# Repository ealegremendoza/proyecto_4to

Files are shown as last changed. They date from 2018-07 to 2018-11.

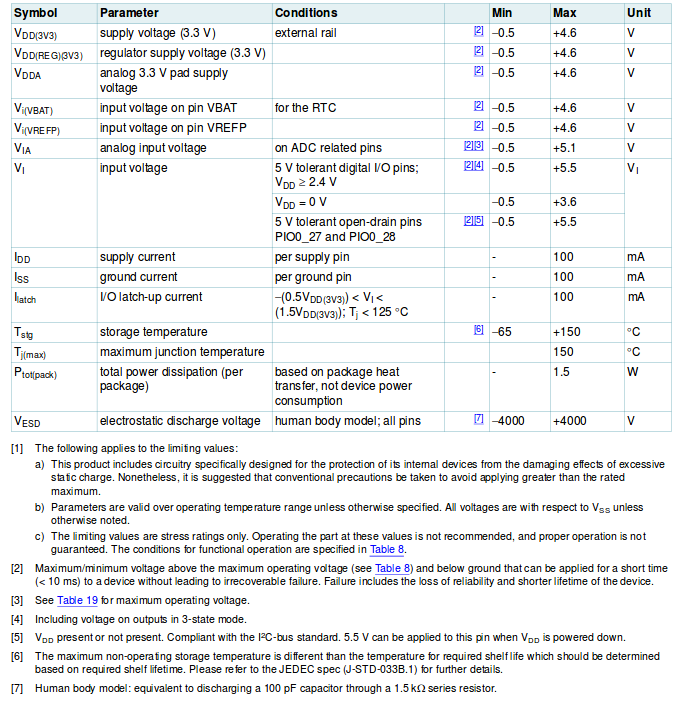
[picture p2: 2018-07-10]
docs/lpc_info/table6_limiting_values.png

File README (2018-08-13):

Este repositorio contiene gran parte del proyecto de cuarto año a de la carrera de Ingeniería Electrónica de la UTN-FRBA.

Breve descripción de las carptas 
---------------------------------------------------------------------------------------------
En la carpeta "docs" se encuentra toda documentación relacionada al proyecto.
En la carpeta "csv" se encuentran los archivos *.csv para la aplicación.

En la carpeta "code" se encuentra todo código relacionado al proyecto.
En la carpeta "code/dsp" se encuentran las clases para el procesamiento de señales.
En la carpeta "code/gui" se encuentran las clases relacionadas a la interfaz gráfica de la aplicación.

En la carpeta "pcb" se encuentra todos los archivos KiCad relacionados al diseño del PCB.

En la carpeta "lpc_info" se encontrará información útil sobre el microcontrolador utilizado.

NOTAS IMPORTANTES
---------------------------------------------------------------------------------------------

- La interfaz gráfica de este proyecto es realizada en código Python 3.6.5., bajo la plataforma ANACONDA3.
- Hoy en día el código funciona en un SO Ubuntu 16.04 LTS.
- Para correr la aplicación:

	Desde la terminal en el directorio code:
		python3 app.py 

	O desde la terminal en el directorio proyecto_4to:
		python3 code/app.py

	Desde SPYDER:
		Abrir el archivo app.py que se encuentra en el directorio code.
		Presionar F5.
---------------------------------------------------------------------------------------------

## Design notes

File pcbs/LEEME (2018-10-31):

PROYECTOS DE KICAD 4.0.7
/misc 	->	footprints, libs.

/pbase 	->	placa base con LPCXPRESSO LPC1769 REVC
/pbase-ino ->	placa base con ARDUINO MEGA
/cargador ->	placa cargadora de baterías de Litio.

placa1-3_G1.zip	-> pbase GERBERS
placa2-3_G1.zip -> cargador GERBERS
placa3-3_G1.zip	-> pbase_ino GERBERS

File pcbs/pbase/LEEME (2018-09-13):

ordenarlos documentos bien antes de entregarlo.

Todos los resistores SMD 0806

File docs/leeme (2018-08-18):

modificar esta carpeta de la siguiente manera:

/docs
	/modulos
	/misc
	/ppt
	/gantt
	/anteproyecto
	/informes
	/manuales

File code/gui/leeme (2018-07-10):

Para correr, en la terminal:

>	python app.py

IMPORTANTE:

Se uso qt designer 5.6 para hacer el *.ui  (archivo interfaz_grafica.ui)

Se uso pyuic5 para convertir este ultimo archivo a extención *.py  (interfaz_grafica_ui.py)

Se uso python 3

Se uso PyQt5

Para convertirr *.ui a *.py hacer lo siguiente:
abrir terminal en el directorio donde esta el archivo *.ui
correr:
pyuic5 test.ui -o test_ui.py

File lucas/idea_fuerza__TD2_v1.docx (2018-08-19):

Using Multiple Sensors and a LCD Display to Determine Football Players Performance

Alegre Ezequiel Mendoza¹, Tarazona Leandro¹, ², Bautista Lucas¹

¹ Universidad Tecnológica Nacional - Facultad Regional Buenos Aires, Argentina

² Grupo de Investigación y Desarrollo en Bioingeniería (GIBIO) Universidad Tecnológica

Nacional- Facultad Regional Buenos Aires, Argentina.

Abstract—. Si bien en el mercado existen productos que permiten estimar parámetros de interés en deportistas, poco se conoce sobre una aplicación que este orientada al mundo de la investigación, capaz de permitirle a un experto tener un monitoreo constante de la actividad física, sin que esta se vea alterada por el seguimiento de la misma. Por ello se busca diseñar un dispositivo portátil de conexionado inalámbrico a fin de determinar la posición, velocidad y distancia total recorrida por un jugador de fútbol en el transcurso de un entrenamiento regular. Haciendo uso de módulos de bajo coste se obtendrán las variables físicas del sujeto así como también se pretende llevar a cabo el cálculo de la incertidumbre en la medición de las mismas. Dado que los sensores proporcionan información de poca fiabilidad, se determinarán estos parámetros mediante técnicas de procesamiento de señales y filtrado digital. Luego a través una interfaz usuario se informara un valor medio de los mismos así como también se realizara el correspondiente respaldo de datos, tanto en la PC como en el dispositivo.

Index Terms—.LCD Display, GPS, ACC’s, IOT, SD Cards, Ciencia y Deportes.

          I. MATERIALES Y METODOS
               A. Diseño y requerimientos

Se propone el desarrollo de un dispositivo portátil capaz de adquirir, enviar y registrar de manera continua la posición y velocidad de un jugador de futbol. El dispositivo debe ser pequeño, funcionar a batería y permitir almacenar los datos durante todo el transcurso del entrenamiento. Para poder realizar un monitoreo de los parámetros de interés el mismo deberá poder conectarse a una interfaz usuario, de manera inalámbrica a través de una PC. El dispositivo se montará sobre el torso del deportista a examinar y para su calibración se lo colocará en una esquina del campo de juego, indicando el encargado de la interfaz usuario la esquina correspondiente. Se encenderá el equipo y, una vez que este finalice la rutina de inicialización, contará con un Display LCD a fin de informar cuando esté listo para usarse. Luego se pulsará un botón de conexión y comenzará una cuenta regresiva la cual debe mostrarse tanto en la interfaz gráfica como en el Display (de no ser así debe repetirse el procedimiento anterior), una vez que la cuenta finalice, el deportista correrá hacia el campo de juego y comenzará el monitoreo.

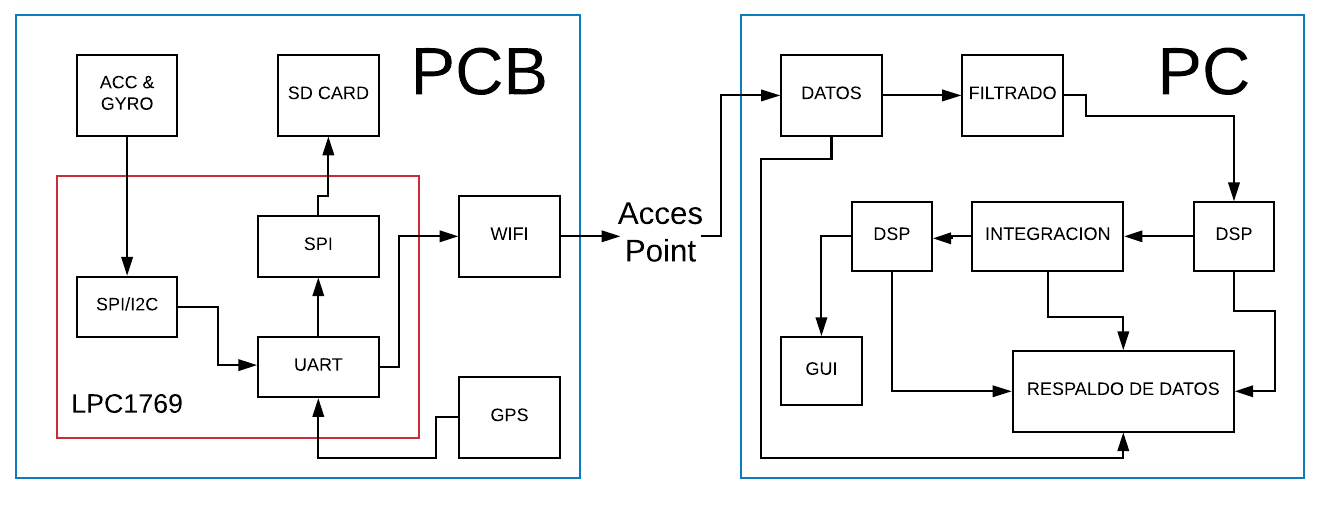
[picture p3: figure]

Fig.1 Diagrama en Bloques: Funcionamiento del Dispositivo.

               B. Hardware

Para la adquisición de las señales de aceleración se utilizará un modulo acelerómetro (MPU 6000/6050) capaz de comunicarse con un micro-controlador del tipo CORTEX M3 a través del protocolo SPI o I²C. Por otro lado la determinación de la posición relativa se obtendrá mediante un modulo GPS el cual entrega tramas de datos vía UART. Para el envió de datos del dispositivo a la PC se utilizará un modulo WI-FI el cual permite enviar tramas de caracteres a través de puerto serie. Para la recepción de los mismos se utilizará un router o acces point que cubra la distancia solicitada. El respaldo de datos se realizará con una memoria SD, la cual tendrá como propósito almacenar los datos del experimento en todo momento en caso de que el equipo sufra una desconexión y finalmente para la alimentación del dispositivo contará con una batería recargable de litio y un puerto de carga para la misma. La HMI contara con botones de acción (ON/OFF, CONNECT) y un Display LCD para informar el estado de la aplicación así como también el tiempo que transcurrió durante el experimento.

               C. Software

Una vez que los datos lleguen a la PC, haciendo uso de Python se realizará el filtrado de los datos mediante la síntesis de un filtro digital que a su vez debe ser capaz de realizar un proceso de integración sobre la variable de entrada. Es necesario efectuar dicho procedimiento ya que el sensor entrega valores referidos a la aceleración y esta se relaciona con la velocidad mediante la ecuación (1). Posteriormente, antes de informar un valor que pueda tomarse como representativo, se realizarán las correcciones correspondientes, como promedio, corrección del error numérico, etc.

a_((t)) =(dv_((t)))/(dt) => ∫ a_((t)) dt=v_((t)) =(dx_((t)))/(dt) => ∫ v_((t)) dt=x_((t))

V_((S)) =1/SA_((S)) => X_((S)) =1/SV_((S)) (1)

X_((S)) =1/S1/SA_((S)) =1/(S^2)A_((S)) (2)

Por otro lado, dado que el GPS presenta un error considerable, se intentará disminuir el mismo mediante la ecuación (2). Esta muestra la relación existente entre la posición y la aceleración, por lo cual resulta necesario hacer pasar la señal de aceleración por un filtro digital de al menos tres etapas, filtrado, integración e integración de la etapa anterior. De este modo procesando los datos del GPS en conjunto con los del acelerómetro puede disminuirse la incertidumbre en la posición del jugador. La interfaz gráfica mostrará la posición y velocidad del jugador en el campo de juego, almacenando a su vez los datos del experimento en una planilla de cálculo para su posterior análisis, el cual estará disponible para el usuario experto en procesamiento de información.

          II. PLANIFICACION DEL PROYECTO
          III. ALCANCE DEL PROYECTO PARA LA ASIGNATURA TECNICAS DIGITALES II

El equipo se compromete a: Desarrollar el hardware necesario, referido a la adquisición, transmisión y respaldo de datos, lograr un sistema embebido de funcionamiento inalámbrico, así como también contar con una interfaz humano-máquina que permita al usuario manipular el dispositivo (puertos de carga, botones de configuración, Display LCD, etc.), priorizando la funcionalidad por sobre el tamaño, estética y practicidad del mismo. Utilizar un micro-controlador del tipo CORTEX M3 para su elaboración. Programar una interfaz gráfica, hecha en Python que reciba los datos del dispositivo e informe al usuario del valor de estos, generando a su vez un respaldo de los mismos. Total transparencia en el armado de la aplicación (circuitos, algoritmos, módulos, código, etc.

Firma Integrantes: …………………………………………………………………………………………

Firma Docentes: ………………………………………………………………………………………....

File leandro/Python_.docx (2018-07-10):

Probar instalando directamente anaconda por este link

https://www.anaconda.com/download/#windows

1 - Instalar Python 2

https://www.python.org/downloads/

2 - Instalar paquetes

Abrir consola de windows y utilizar los siguientes comandos

python -mpip install -U pip
python -mpip install -U matplotlib

3 - Implementar los paquetes

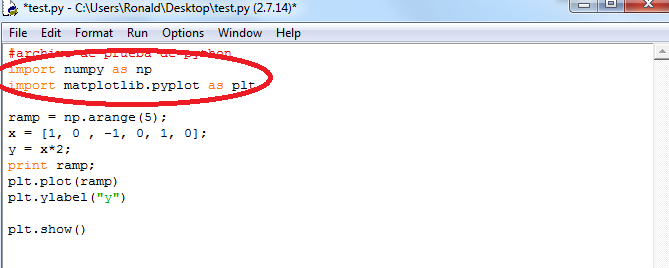
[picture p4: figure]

4 - Utilizar matplotlib y numpy

5 - Para ayuda con sintaxis y otras cosas revisar el Help-> PythonDocs o code academy :

https://www.codecademy.com/learn/learn-python

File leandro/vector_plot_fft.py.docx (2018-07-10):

#archivo de prueba de python

import numpy as np #libreria de matrices

import matplotlib.pyplot as plt #para plots

import scipy.fftpack # para fft

N = 20

ramp = (np.arange(N))/float(N); #creo un vector con una rampa creciente de 0 a 1

ramp_fft = scipy.fftpack.fft(ramp, N , 0); #FFT de la rampa

## Creacion de los gráficos ###############################

# Seteo un tamaño mas grande para los graficos

plt.rcParams['figure.figsize'] = (20,10)

# Grafico de la rampa

fig1, ax = plt.subplots()

ax.plot(ramp)

plt.ylabel("ramp")

# Grafico del modulo de la fft de la rampa

fig2, bx = plt.subplots()

bx.plot(abs(ramp_fft))

plt.ylabel("fft")

plt.show()

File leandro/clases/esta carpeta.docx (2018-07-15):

Los siguientes archivos son ejemplos de clases en python.

No estan comentados pero estan listos para correr.

El archivo .ipynb es para abrir con jupyter

los otros dos son los archivos listos para usar en spyder o python a secas.

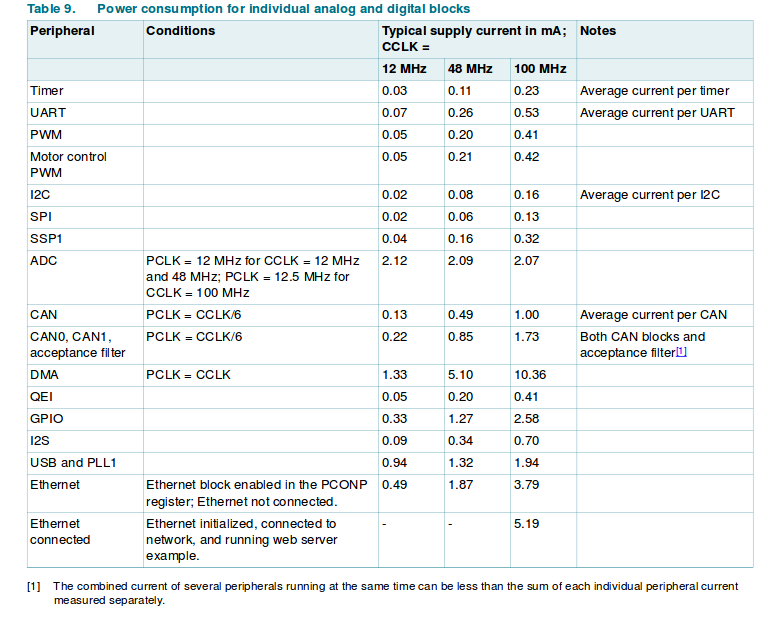
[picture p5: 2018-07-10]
docs/lpc_info/table9_power_consumption_for_individual_analog_and_digital_blocks.png

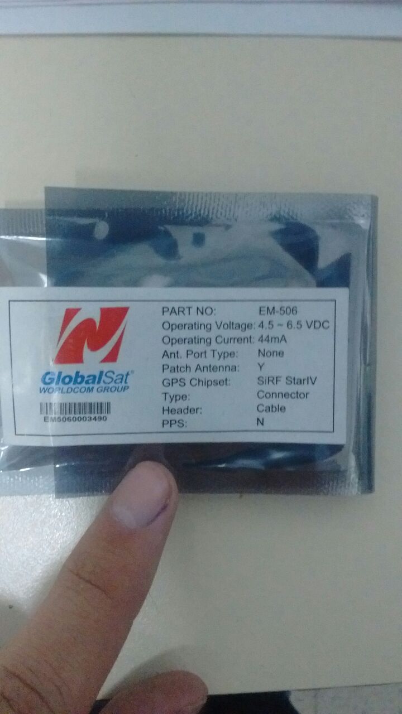
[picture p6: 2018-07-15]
docs/modulos/GPS/modulo gps que consigio lucas.jpg

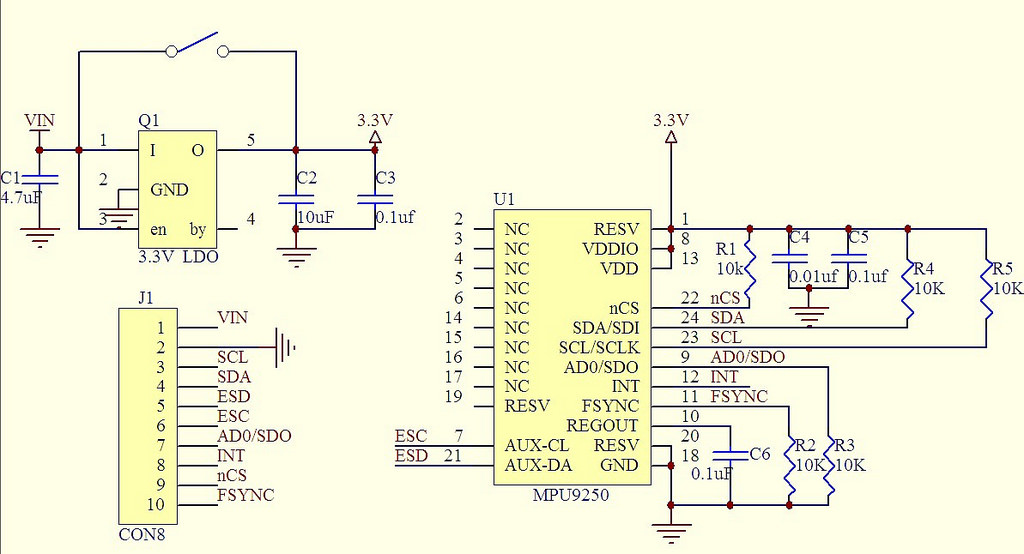
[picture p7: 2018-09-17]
docs/modulos/acc/mpu9250_board_sch.jpg

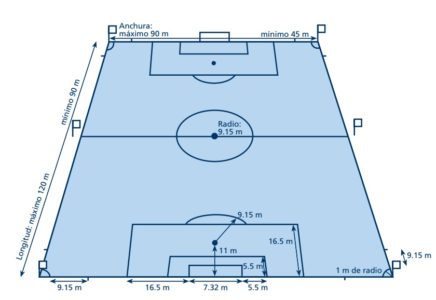
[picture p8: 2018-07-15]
docs/misc/cancha_fubol_dimensiones.jpg

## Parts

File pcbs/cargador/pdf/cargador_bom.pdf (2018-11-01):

cargador

Page 1

Count: | 26
Comp:
Item | Qty | Reference(s) | Value | LibPart | Footprint
| 1 BT1 | | Battery | Battery | Battery_Holders:Bulgin_BX0036_1xC
| 1 C1 | | 10uF | CP | Capacitors_Tantalum_SMD:CP_Tantalum_Case-A_EIA-3216-18_Hand
| 1 C2 | | 0.1uF | C | Capacitors_SMD:C_0805_HandSoldering
| 1 C3 | | 0.22uF | C | Capacitors_SMD:C_0805_HandSoldering
| 1 C4 | | 1uF | C | Capacitors_SMD:C_0805_HandSoldering
| 1 C5 | | 100uF | CP | Capacitors_SMD:CP_Elec_6.3x5.3
| 1 C6 | | 0.47uF | C | Capacitors_Tantalum_SMD:CP_Tantalum_Case-A_EIA-3216-18_Hand
| 1 C7 | | 47uF | CP | Capacitors_Tantalum_SMD:CP_Tantalum_Case-C_EIA-6032-28_Hand
| 1 C8 | | 330u 16V | CP | Capacitors_SMD:CP_Elec_6.3x7.7 (o sino 8x10, o sino 8x10.5)
| 1 C9 | | 10pF | C | Capacitors_SMD:C_0805_HandSoldering
| 1 D1 | | LED | LED | LEDs:LED_1206_HandSoldering
| 1 D2 | | 1N5817 | D_Schottky | Diodes_THT:D_DO-41_SOD81_P7.62mm_Horizontal
| 1 J1 | | Barrel_Jack | conn:Barrel_Jack | Connectors:BARREL_JACK
| 1 J2 | | Conn_01x04_Male | Conn_01x04_Male | Pin_Headers:Pin_Header_Straight_1x04_Pitch2.54mm
| 3 JP1, JP2, JP3 | | Jumper | Jumper | Pin_Headers:Pin_Header_Straight_1x02_Pitch2.54mm
| 1 L1 | | 330uH | L_Core_Ferrite | footprints:Choke_PK0810
| 1 R1 | | 0.1 | R | Resistors_SMD:R_2512_HandSoldering
| 1 R2 | | 120 R | | Resistors_SMD:R_0805_HandSoldering
| 1 R3 | | 1k | R | Resistors_SMD:R_0805_HandSoldering
| 1 R4 | | 470 R | | Resistors_SMD:R_0805_HandSoldering
| 1 TH1 | | 10K | Thermistor_NTC | R THT:R_Axial_DIN0207_L6.3mm_D2.5mm_P2.54mm. Ancho pata <0,8mm
| 1 U1 | | BQ24004 | bq24004:BQ24004 | Housings_SSOP:HTSSOP-20-1EP_4.4x6.5mm_Pitch0.65mm_ThermalPad
| 1 U2 | | LM2940-5V | lm2940:LM2940-5V | TO_SOT_Packages_SMD:SOT-223-3_TabPin2
| 1 U3 | | LM2575-3.3 (*) | lm2575:LM2575-3.3 | TO_SOT_Packages_SMD:TO-263-5_TabPin3
(*) De no conseguir LM2575-3.3V Un buen reemplazo es el LM2596-3.3V que tiene el mismo circuito, pero con diferentes valores de componentes.
1 U3 | LM2596-3.3V | TO-263
1 L1 | 47uH | Radial pitch 5mm THT | PK0707. CODIGO ELEMON: FI1535090
1 D1 | 1N5817 / 1N15819 / 1N5822 | D_Schottky | Axial. Cualquiera de los 3: 1N5817 / 1N15819 / 1N5822 . THT
2 C5,C8 | 330uFx16V | | Capacitors_SMD:CP_Elec_6.3x5.3 (o sino 6.3x7.7, 8x10, 8x10.5)

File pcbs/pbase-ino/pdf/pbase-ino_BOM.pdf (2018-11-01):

pbase-ino

Page 1

Count: | 31
Item | Qty | Ref | Value | LibPart | Footprint
| 1 C1 | | 1uF x 16V | CP | C SMD:CP_Tantalum_Case-A_EIA-3216-18
| 1 C2 | | 100n | C | Capacitors_SMD:C_0805
| 1 C3 | | 100u | CP | Capacitors_SMD:CP_Elec_6.3x5.3
| 1 C4 | | 330u | CP | Capacitors_SMD:CP_Elec_10x10.5
| 1 D1 | | 1N5817 | D_Schottky | Diodes_THT:D_DO-41_SOD81_P7.62mm_Horizontal
| 1 J1 | | SD Oupiin 9004-BA09W01C00A | SD_Card CONN | SD_TE_2041021_edit
| 2 J2,SW1 | | Screw_Terminal_01x02 | BORNERA-2 P5.08mm | TerminalBlock_bornier-2_P5.08mm
| 1 L1 | | 330uH | L_Core_Ferrite | Choke_PK0810
| 1 R1 | | 0R | R | R SMD:R_0805
| 2 R2, R3 | | 10K | R | R SMD:R_0805
| 3 R4,R5,R6 | | 1K8 | R | R SMD:R_0805
| 3 R7,R8,R9 | | 3K3 | R | R SMD:R_0805
| 1 U1 | | LM2575-3.3 | lm2575:LM2575-3.3 | TO_SOT_Packages_SMD:TO-263-5_TabPin3
| 1 U3 | | GPS_EM506 | GPS_EM506 | Conn JST_SH_SM06B-SRSS-TB_06x1.00mm_Angled
| 2 | | TIRA PIN MACHO 1x40 P2.54mm | (1x26)+(1x26)+(1x10) | Para arduino MEGA y acelerómetro mpu9250
| 1 | | TIRA PIN MACHO 2X40 P2.54mm | Necesita 1 tira de 2x20 | Para arduino MEGA
| 1 | | TIRA PIN HEMBRA 2X05 P2.54mm | TIRA PIN HEMBRA 2X05 P2.54mm Para arduino MEGA
| 2 | | TIRA PIN HEMBRA 2X10 P2mm | TIRA PIN HEMBRA 2X10 P2mm | Para XBEE. Tamb pueden ser 2 tiras 1x10 P2mm
1 MOD1 | XBEE/XBEE-PRO | XBE / XBEE-PRO | xbee_xb24cz7pit_004
1 U2 | acc_mpu9250_board | acc_mpu9250_board | mpu9250_board
1 | GPS_EM506 | gps em506 | gps em506
1 XA1 | Arduino_Mega2560_Shield | arduino:Arduino_Mega2560_Shield | Arduino_Mega2560_Shield_flippedONtop

(*) De no conseguir LM2575-3.3V Un buen reemplazo es el LM2596-3.3V que tiene el mismo circuito, pero con diferentes valores de componentes.
1 U3 | LM2596-3.3V | TO-263
1 L1 | 47uH | Radial pitch 5mm THT | PK0707. CODIGO ELEMON: FI1535090
1 D1 | 1N5817 / 1N15819 / 1N5822 | D_Schottky | Axial. Cualquiera de los 3: 1N5817 / 1N15819 / 1N5822 . THT
2 C5,C8 | 330uFx16V | | Capacitors_SMD:CP_Elec_6.3x5.3 (o sino 6.3x7.7, 8x10, 8x10.5)

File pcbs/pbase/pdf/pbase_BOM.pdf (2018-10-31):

pbase

Page 1

Count: | 22
Comp:
Item | Qty | Ref | Value | LibPart | Footprint
| 1 C1 | | 1uF x 16V | CP | C SMD:CP_Tantalum_Case-A_EIA-3216-18_Hand
| 1 C2 | | 100n | C | C SMD:C_0805_HandSoldering
| 1 J1 | | SD Oupiin 9004-BA09W01C00A | conn:SD_Card | SD_TE_2041021_edit
| 1 R1 | | 0R | R | R SMD:R_0805_HandSoldering
| 2 R2, R3 | | 10K | R | R SMD:R_0805_HandSoldering
| 2 R4, R5 | | 33K | R | R SMD:R_0805_HandSoldering
| 1 R6 | | RD1 | R | R SMD:R_0805_HandSoldering
| 1 R7 | | RD2 | R | R SMD:R_0805_HandSoldering
| 1 U3 | | GPS_EM506 | GPS_EM506 | Conn JST_SH_SM06B-SRSS-TB_06x1.00mm_Angled
| 2 | | Conn_02x10 | PINES HEMBRA 2X10 p2mm | Para el zigbee. Si no se consigue ? 2 TIRAS PINES HEMBRA 1X10
| 2 | | PINES HEMBRA 1X40 P2.54mm | PINES HEMBRA 1X40 P2.54mm | Para lpc1769,acelerómetro, PWR y display.
1 U1 | LPCXpresso_LPC1769_revc | LPCXpresso_LPC1769_revc | lpc1769_board_revC
1 U2 | acc_mpu9250_board | acc_mpu9250_board | mpu9250_board
1 U3.1 | GPS_EM506 | GPS_EM506 | GPS EM506
1 MOD1 | XB24CZ7PIT-004 | XBEE / XBEE-PRO | xbee_xb24cz7pit_004

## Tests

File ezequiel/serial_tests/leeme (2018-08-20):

#USO
0) Conectar arduino a la pc.
1) abrir arduino IDE y bajar el archivo *.ino
2) en una consola o en spyder correr el codigo *.py

#NOTA:Se deben contar con permisos para acceder al puerto serie.

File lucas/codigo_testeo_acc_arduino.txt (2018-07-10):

http://www.circuitstoday.com/interfacing-accelerometer-to-arduino

codigo de prueba acc con arduino por i2c

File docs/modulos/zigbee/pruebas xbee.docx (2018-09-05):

Pruebas con arduino nano y xctu a un baud rate de 115200

Enviando caracteres de la forma mostrada se obtiene esa trama. Notese que se recibe 1 byte por cada Serial.write().

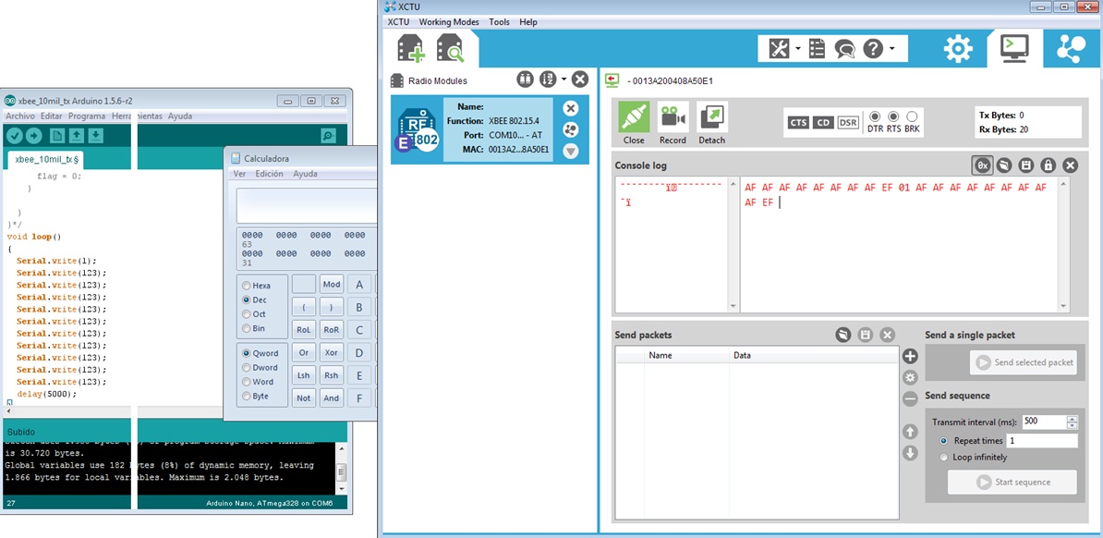
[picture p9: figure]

Enviando en un vector de bytes llega de forma extraña. Por momentos llegan 4 o 5 bytes y en otros un solo byte.

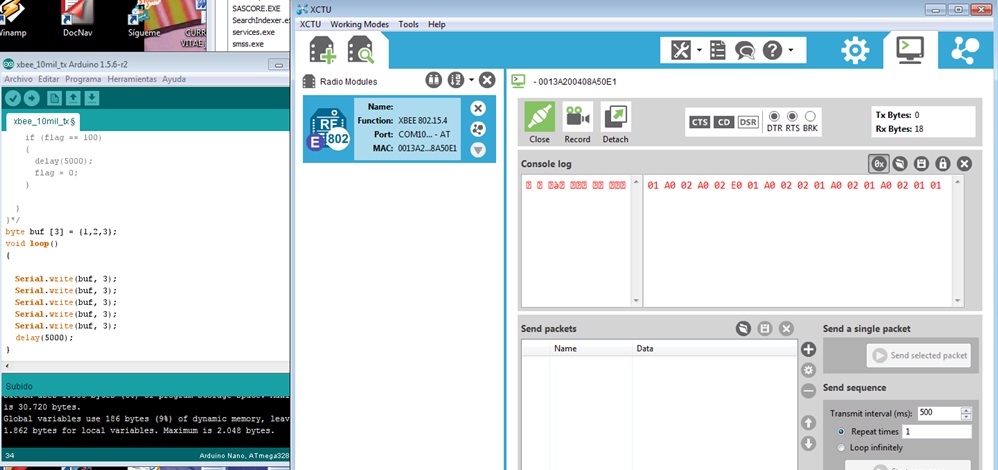
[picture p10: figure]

Enviando un solo paquete se obtiene el siguiente resultado en el mejor de los casos

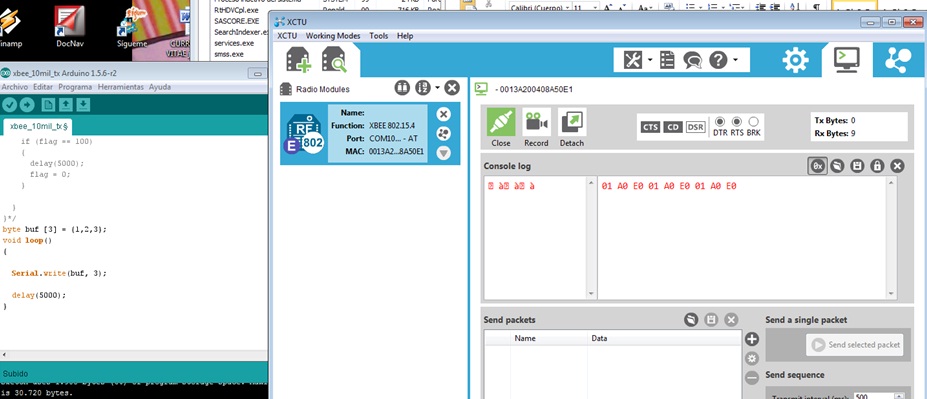
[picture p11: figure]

En 3 ciclos se obtiene lo siguiente para el código enviando 2 tramas (1,2,3 y 4, 5,6)

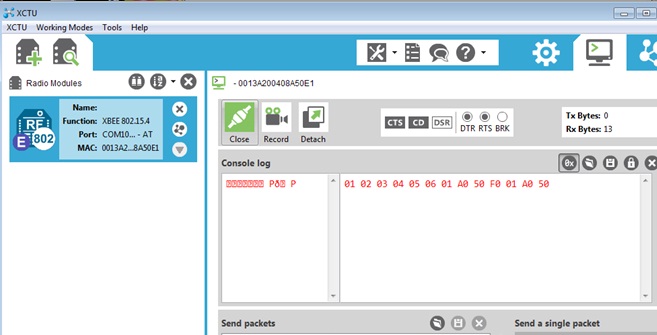
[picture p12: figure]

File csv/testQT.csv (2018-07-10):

col1 | col2
0 | 0
1 | 0
2 | 1
3 | 2
4 | 3
5 | 4
6 | -4
7 | 2
8 | 4
9 | 8
10 | 3
11 | 1
12 | 8
13 | 6
14 | 1
15 | 0

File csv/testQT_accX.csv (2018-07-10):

col1 | col2
18:26.3 | 1904
18:26.3 | 1908
18:26.3 | 1907
18:26.3 | 1899
18:26.3 | 1906
18:26.3 | 1902
18:26.3 | 1900
18:26.3 | 1907
18:26.3 | 1903
18:26.3 | 1900
18:26.3 | 1903
18:26.3 | 1899
18:26.3 | 1901
18:26.3 | 1899
18:26.4 | 1898
18:26.4 | 1907
18:26.4 | 1904
18:26.4 | 1899
18:26.4 | 1899
18:26.4 | 1899
18:26.4 | 1905
18:26.4 | 1897
18:26.4 | 1904
18:26.4 | 1904
18:26.4 | 1900
18:26.4 | 1898
18:26.4 | 1901
18:26.4 | 1900
18:26.4 | 1903
18:26.4 | 1902
18:26.4 | 1904
18:26.4 | 1902
18:26.4 | 1900
18:26.4 | 1904
18:26.4 | 1898
18:26.4 | 1903
18:26.4 | 1901
18:26.4 | 1902
18:26.4 | 1897
18:26.4 | 1899
18:26.4 | 1906
18:26.4 | 1907
18:26.4 | 1901
18:26.4 | 1904
18:26.4 | 1906
18:26.4 | 1907
18:26.4 | 1901
18:26.4 | 1904
18:26.4 | 1902
18:26.4 | 1904
18:26.4 | 1899
18:26.4 | 1908
18:26.4 | 1908
18:26.4 | 1900
18:26.4 | 1899
18:26.4 | 1905
18:26.4 | 1902
18:26.4 | 1907
18:26.4 | 1899
18:26.4 | 1904
18:26.4 | 1901
18:26.4 | 1898
18:26.4 | 1897
18:26.4 | 1903
18:26.4 | 1900
18:26.5 | 1897
18:26.5 | 1900
18:26.5 | 1899
18:26.5 | 1903
18:26.5 | 1902
18:26.5 | 1899
18:26.5 | 1906
18:26.5 | 1907
18:26.5 | 1906
18:26.5 | 1904
18:26.5 | 1902
18:26.5 | 1907
18:26.5 | 1908
18:26.5 | 1905
18:26.5 | 1903
18:26.5 | 1902
18:26.5 | 1904
18:26.5 | 1900
18:26.5 | 1900
18:26.5 | 1901
18:26.5 | 1899
18:26.5 | 1900
18:26.5 | 1899
18:26.5 | 1901
18:26.5 | 1898
18:26.5 | 1897
18:26.5 | 1895
18:26.5 | 1898
18:26.5 | 1897
18:26.5 | 1898
18:26.5 | 1894
18:26.5 | 1896
18:26.5 | 1894
18:26.5 | 1891
18:26.5 | 1898
18:26.5 | 1901
18:26.5 | 1897
18:26.5 | 1905
18:26.5 | 1907
18:26.5 | 1905
18:26.5 | 1890
18:26.5 | 1892
18:26.5 | 1894
18:26.5 | 1899
18:26.5 | 1898
18:26.5 | 1900
18:26.5 | 1905
18:26.5 | 1892
18:26.5 | 1897
18:26.5 | 1899
18:26.5 | 1899
18:26.6 | 1900
18:26.6 | 1900
18:26.6 | 1905
18:26.6 | 1907
18:26.6 | 1906
18:26.6 | 1911
18:26.6 | 1907
18:26.6 | 1905
18:26.6 | 1904
18:26.6 | 1907
18:26.6 | 1911
18:26.6 | 1911
18:26.6 | 1916
18:26.6 | 1918
18:26.6 | 1912
18:26.6 | 1909
18:26.6 | 1915
18:26.6 | 1915
18:26.6 | 1905
18:26.6 | 1902
18:26.6 | 1906
18:26.6 | 1899
18:26.6 | 1892
18:26.6 | 1894
18:26.6 | 1899
18:26.6 | 1898
18:26.6 | 1901
18:26.6 | 1906
18:26.6 | 1907
18:26.6 | 1904
18:26.6 | 1912
18:26.6 | 1905
18:26.6 | 1903
18:26.6 | 1910
18:26.6 | 1908
18:26.6 | 1917
18:26.6 | 1921
18:26.6 | 1910
18:26.6 | 1904
18:26.6 | 1916
18:26.6 | 1923
18:26.6 | 1922
18:26.6 | 1922
18:26.6 | 1930
18:26.6 | 1935
18:26.6 | 1930
18:26.6 | 1948
18:26.6 | 1950
18:26.6 | 1954
18:26.6 | 1971
18:26.6 | 1976
18:26.7 | 1968
18:26.7 | 1961
18:26.7 | 1949
18:26.7 | 1957
18:26.7 | 1960
18:26.7 | 1961
18:26.7 | 1958
18:26.7 | 1969
18:26.7 | 1972
18:26.7 | 1969
18:26.7 | 1963
18:26.7 | 1959
18:26.7 | 1953
18:26.7 | 1957
18:26.7 | 1959
18:26.7 | 1945
18:26.7 | 1950
18:26.7 | 1951
18:26.7 | 1951
18:26.7 | 1940
18:26.7 | 1935
18:26.7 | 1888
18:26.7 | 1829
18:26.7 | 1795
18:26.7 | 1915
18:26.7 | 1965
18:26.7 | 1914
18:26.7 | 1852
18:26.7 | 1860
18:26.7 | 1891
18:26.7 | 1879
18:26.7 | 1860
18:26.7 | 1849
18:26.7 | 1875
18:26.7 | 1892
18:26.7 | 1883
18:26.7 | 1873
18:26.7 | 1885
18:26.7 | 1887
18:26.7 | 1890
18:26.7 | 1889
18:26.7 | 1896
18:26.7 | 1895
18:26.7 | 1884
18:26.7 | 1888
18:26.7 | 1891
18:26.7 | 1891
18:26.7 | 1891
18:26.7 | 1900
18:26.7 | 1885
18:26.7 | 1890
18:26.8 | 1888
18:26.8 | 1882
18:26.8 | 1888
18:26.8 | 1881
18:26.8 | 1887
18:26.8 | 1884
18:26.8 | 1879
18:26.8 | 1879
18:26.8 | 1872
18:26.8 | 1873
18:26.8 | 1865
18:26.8 | 1863
18:26.8 | 1853
18:26.8 | 1854
18:26.8 | 1854
18:26.8 | 1876
18:26.8 | 1882
18:26.8 | 1878
18:26.8 | 1868
18:26.8 | 1883
18:26.8 | 1893
18:26.8 | 1912
18:26.8 | 1919
18:26.8 | 1934
18:26.8 | 1937
18:26.8 | 1927
18:26.8 | 1914
18:26.8 | 1899
18:26.8 | 1890
18:26.8 | 1890
18:26.8 | 1897
18:26.8 | 1901
18:26.8 | 1899
18:26.8 | 1907
18:26.8 | 1917
18:26.8 | 1914
18:26.8 | 1916
18:26.8 | 1915
18:26.8 | 1917
18:26.8 | 1908
18:26.8 | 1903
18:26.8 | 1905
18:26.8 | 1903
18:26.8 | 1901
18:26.8 | 1904
18:26.8 | 1910
18:26.8 | 1922
18:26.8 | 1917
18:26.8 | 1918
18:26.8 | 1910
18:26.8 | 1913
18:26.8 | 1912
18:26.9 | 1913
18:26.9 | 1908
18:26.9 | 1911
18:26.9 | 1911
18:26.9 | 1914
18:26.9 | 1906
18:26.9 | 1907
18:26.9 | 1911
18:26.9 | 1904
18:26.9 | 1895
18:26.9 | 1894
18:26.9 | 1902
18:26.9 | 1904
18:26.9 | 1906
18:26.9 | 1896
18:26.9 | 1891
18:26.9 | 1890
18:26.9 | 1883
18:26.9 | 1884
18:26.9 | 1877
18:26.9 | 1885
18:26.9 | 1884
18:26.9 | 1878
18:26.9 | 1868
18:26.9 | 1863
18:26.9 | 1852
18:26.9 | 1847
18:26.9 | 1846
18:26.9 | 1838
18:26.9 | 1851
18:26.9 | 1863
18:26.9 | 1862
18:26.9 | 1863
18:26.9 | 1870
18:26.9 | 1872
18:26.9 | 1874
18:26.9 | 1863
18:26.9 | 1849
18:26.9 | 1863
18:26.9 | 1860
18:26.9 | 1857
18:26.9 | 1854
18:26.9 | 1841
18:26.9 | 1842
18:26.9 | 1846
18:26.9 | 1830
18:26.9 | 1861
18:26.9 | 1876
18:26.9 | 1894
18:26.9 | 1909
18:26.9 | 1930
18:27.0 | 1939
18:27.0 | 1933
18:27.0 | 1940
18:27.0 | 1932
18:27.0 | 1933
18:27.0 | 1937
18:27.0 | 1939
18:27.0 | 1936
18:27.0 | 1925
18:27.0 | 1921
18:27.0 | 1921
18:27.0 | 1923
18:27.0 | 1929
18:27.0 | 1939
18:27.0 | 1945
18:27.0 | 1950
18:27.0 | 1945
18:27.0 | 1948
18:27.0 | 1953
18:27.0 | 1947
18:27.0 | 1949
18:27.0 | 1941
18:27.0 | 1946
18:27.0 | 1942
18:27.0 | 1942
18:27.0 | 1943
18:27.0 | 1952
18:27.0 | 1951
18:27.0 | 1947
18:27.0 | 1949
18:27.0 | 1947
18:27.0 | 1940
18:27.0 | 1924
18:27.0 | 1923
18:27.0 | 1911
18:27.0 | 1906
18:27.0 | 1897
18:27.0 | 1895
18:27.0 | 1893
18:27.0 | 1890
18:27.0 | 1871
18:27.0 | 1854
18:27.0 | 1839
18:27.0 | 1836
18:27.0 | 1846
18:27.0 | 1851
18:27.0 | 1863
18:27.0 | 1864
18:27.0 | 1870
18:27.0 | 1878
18:27.0 | 1875
18:27.1 | 1871
18:27.1 | 1877
18:27.1 | 1863
18:27.1 | 1854
18:27.1 | 1853
18:27.1 | 1856
18:27.1 | 1855
18:27.1 | 1847
18:27.1 | 1846
18:27.1 | 1853
18:27.1 | 1856
18:27.1 | 1859
18:27.1 | 1859
18:27.1 | 1842
18:27.1 | 1842
18:27.1 | 1843
18:27.1 | 1862
18:27.1 | 1867
18:27.1 | 1872
18:27.1 | 1884
18:27.1 | 1891
18:27.1 | 1908
18:27.1 | 1939
18:27.1 | 1979
18:27.1 | 1979
18:27.1 | 1957
18:27.1 | 1944
18:27.1 | 1904
18:27.1 | 1899
18:27.1 | 1902
18:27.1 | 1907
18:27.1 | 1915
18:27.1 | 1914
18:27.1 | 1909
18:27.1 | 1922
18:27.1 | 1939
18:27.1 | 1947
18:27.1 | 1930
18:27.1 | 1928
18:27.1 | 1923
18:27.1 | 1924
18:27.1 | 1926
18:27.1 | 1931
18:27.1 | 1923
18:27.1 | 1921
18:27.1 | 1913
18:27.1 | 1908
18:27.1 | 1894
18:27.1 | 1884
18:27.1 | 1925
18:27.1 | 1895
18:27.2 | 1858
18:27.2 | 1845
18:27.2 | 1858
18:27.2 | 1892
18:27.2 | 1921
18:27.2 | 1887
18:27.2 | 1884
18:27.2 | 1900
18:27.2 | 1907
18:27.2 | 1904
18:27.2 | 1917
18:27.2 | 1923
18:27.2 | 1915
18:27.2 | 1918
18:27.2 | 1917
18:27.2 | 1905
18:27.2 | 1882
18:27.2 | 1863
18:27.2 | 1868
18:27.2 | 1911
18:27.2 | 1942
18:27.2 | 1987
18:27.2 | 1918
18:27.2 | 1923
18:27.2 | 1924
18:27.2 | 1925
18:27.2 | 1924
18:27.2 | 1924
18:27.2 | 1923
18:27.2 | 1923
18:27.2 | 1914
18:27.2 | 1922
18:27.2 | 1919
18:27.2 | 1906
18:27.2 | 1921
18:27.2 | 1937
18:27.2 | 1928
18:27.2 | 1899
18:27.2 | 1848
18:27.2 | 1795
18:27.2 | 1772
18:27.2 | 1773
18:27.2 | 1782
18:27.2 | 1803
18:27.2 | 1838
18:27.2 | 1873
18:27.2 | 1883
18:27.2 | 1876
18:27.2 | 1876
18:27.2 | 1896
18:27.2 | 1937
18:27.3 | 1923
18:27.3 | 1889
18:27.3 | 1902
18:27.3 | 1876
18:27.3 | 1856
18:27.3 | 1845
18:27.3 | 1828
18:27.3 | 1814
18:27.3 | 1791
18:27.3 | 1801
18:27.3 | 1828
18:27.3 | 1809
18:27.3 | 1776
18:27.3 | 1877
18:27.3 | 1922
18:27.3 | 1940
18:27.3 | 2011
18:27.3 | 2037
18:27.3 | 2054
18:27.3 | 2028
18:27.3 | 1935
18:27.3 | 1882
18:27.3 | 1908
18:27.3 | 1976
18:27.3 | 2011
18:27.3 | 1943
18:27.3 | 1908
18:27.3 | 1934
18:27.3 | 1913
18:27.3 | 1897
18:27.3 | 1895
18:27.3 | 1918
18:27.3 | 1929
18:27.3 | 1933
18:27.3 | 1922
18:27.3 | 1902
18:27.3 | 1896
18:27.3 | 1935
18:27.3 | 1999
18:27.3 | 1960
18:27.3 | 1864
18:27.3 | 1843
18:27.3 | 1926
18:27.3 | 1980
18:27.3 | 1960
18:27.3 | 1892
18:27.3 | 1842
18:27.3 | 1823
18:27.3 | 1903
18:27.3 | 1956
18:27.3 | 1962
18:27.3 | 1967
18:27.4 | 1936
18:27.4 | 1905
18:27.4 | 1901
18:27.4 | 1905
18:27.4 | 1894
18:27.4 | 1837
18:27.4 | 1811
18:27.4 | 1818
18:27.4 | 1835
18:27.4 | 1842
18:27.4 | 1867
18:27.4 | 1947
18:27.4 | 1951
18:27.4 | 1997
18:27.4 | 2021
18:27.4 | 2014
18:27.4 | 1966
18:27.4 | 1929
18:27.4 | 1922
18:27.4 | 1932
18:27.4 | 1973
18:27.4 | 1990
18:27.4 | 1958
18:27.4 | 1910
18:27.4 | 1882
18:27.4 | 1894
18:27.4 | 1939
18:27.4 | 1959
18:27.4 | 1972
18:27.4 | 1960
18:27.4 | 1955
18:27.4 | 1944
18:27.4 | 1929
18:27.4 | 1923
18:27.4 | 1927
18:27.4 | 1903
18:27.4 | 1915
18:27.4 | 1965
18:27.4 | 2005
18:27.4 | 2020
18:27.4 | 1986
18:27.4 | 1957
18:27.4 | 1967
18:27.4 | 1961
18:27.4 | 1962
18:27.4 | 1961
18:27.4 | 1966
18:27.4 | 1956
18:27.4 | 1933
18:27.4 | 1909
18:27.4 | 1883
18:27.5 | 1863
18:27.5 | 1847
18:27.5 | 1842
18:27.5 | 1853
18:27.5 | 1863
18:27.5 | 1898
18:27.5 | 1916
18:27.5 | 1929
18:27.5 | 1935
18:27.5 | 1937
18:27.5 | 1933
18:27.5 | 1922
18:27.5 | 1908
18:27.5 | 1879
18:27.5 | 1843
18:27.5 | 1818
18:27.5 | 1830
18:27.5 | 1835
18:27.5 | 1823
18:27.5 | 1793
18:27.5 | 1804
18:27.5 | 1820
18:27.5 | 1830
18:27.5 | 1869
18:27.5 | 1895
18:27.5 | 1943
18:27.5 | 2002
18:27.5 | 2029
18:27.5 | 1993
18:27.5 | 1917
18:27.5 | 1897
18:27.5 | 1954
18:27.5 | 1984
18:27.5 | 1995
18:27.5 | 1986
18:27.5 | 1963
18:27.5 | 1919
18:27.5 | 1902
18:27.5 | 1925
18:27.5 | 1926
18:27.5 | 1926
18:27.5 | 1923
18:27.5 | 1921
18:27.5 | 1955
18:27.5 | 1978
18:27.5 | 1951
18:27.5 | 1902
18:27.5 | 1870
18:27.5 | 1888
18:27.5 | 1909
18:27.5 | 1891
18:27.6 | 1878
18:27.6 | 1890
18:27.6 | 1901
18:27.6 | 1907
18:27.6 | 1876
18:27.6 | 1863
18:27.6 | 1876
18:27.6 | 1892
18:27.6 | 1889
18:27.6 | 1915
18:27.6 | 1922
18:27.6 | 1916
18:27.6 | 1898
18:27.6 | 1895
18:27.6 | 1905
18:27.6 | 1900
18:27.6 | 1883
18:27.6 | 1864
18:27.6 | 1851
18:27.6 | 1852
18:27.6 | 1864
18:27.6 | 1865
18:27.6 | 1889
18:27.6 | 1932
18:27.6 | 1932
18:27.6 | 1944
18:27.6 | 1983
18:27.6 | 2030
18:27.6 | 2054
18:27.6 | 2005
18:27.6 | 1953
18:27.6 | 1933
18:27.6 | 1930
18:27.6 | 1967
18:27.6 | 1974
18:27.6 | 1920
18:27.6 | 1906
18:27.6 | 1925
18:27.6 | 1934
18:27.6 | 1955
18:27.6 | 1963
18:27.6 | 1967
18:27.6 | 1976
18:27.6 | 1963
18:27.6 | 1948
18:27.6 | 1946
18:27.6 | 1964
18:27.6 | 1970
18:27.6 | 1978
18:27.6 | 1983
18:27.6 | 1979
18:27.7 | 1973
18:27.7 | 1959
18:27.7 | 1949
18:27.7 | 1919
18:27.7 | 1892
18:27.7 | 1862
18:27.7 | 1869
18:27.7 | 1883
18:27.7 | 1883
18:27.7 | 1913
18:27.7 | 1923
18:27.7 | 1929
18:27.7 | 1935
18:27.7 | 1924
18:27.7 | 1898
18:27.7 | 1907
18:27.7 | 1902
18:27.7 | 1902
18:27.7 | 1914
18:27.7 | 1926
18:27.7 | 1904
18:27.7 | 1935
18:27.7 | 1975
18:27.7 | 1959
18:27.7 | 1981
18:27.7 | 2019
18:27.7 | 2079
18:27.7 | 2077
18:27.7 | 2005
18:27.7 | 1950
18:27.7 | 1907
18:27.7 | 1930
18:27.7 | 1944
18:27.7 | 1957
18:27.7 | 1934
18:27.7 | 1912
18:27.7 | 1927
18:27.7 | 1949
18:27.7 | 1956
18:27.7 | 1967
18:27.7 | 1969
18:27.7 | 1981
18:27.7 | 1967
18:27.7 | 1955
18:27.7 | 1961
18:27.7 | 1975
18:27.7 | 1967
18:27.7 | 1966
18:27.7 | 1981
18:27.7 | 1983
18:27.7 | 1948
18:27.8 | 1943
18:27.8 | 1929
18:27.8 | 1921
18:27.8 | 1922
18:27.8 | 1934
18:27.8 | 1922
18:27.8 | 1902
18:27.8 | 1894
18:27.8 | 1892
18:27.8 | 1928
18:27.8 | 1975
18:27.8 | 1993
18:27.8 | 1965
18:27.8 | 1900
18:27.8 | 1846
18:27.8 | 1841
18:27.8 | 1861
18:27.8 | 1886
18:27.8 | 1918
18:27.8 | 1963
18:27.8 | 1978
18:27.8 | 1994
18:27.8 | 2006
18:27.8 | 1989
18:27.8 | 2004
18:27.8 | 2031
18:27.8 | 2032
18:27.8 | 2006
18:27.8 | 1972
18:27.8 | 1953
18:27.8 | 1967
18:27.8 | 1965
18:27.8 | 1968
18:27.8 | 1979
18:27.8 | 1955
18:27.8 | 1952
18:27.8 | 1961
18:27.8 | 1967
18:27.8 | 1978
18:27.8 | 1977
18:27.8 | 1976
18:27.8 | 1974
18:27.8 | 1985
18:27.8 | 1991
18:27.8 | 1998
18:27.8 | 1991
18:27.8 | 2000
18:27.8 | 1991
18:27.8 | 1977
18:27.8 | 1982
18:27.8 | 1950
18:27.8 | 1955
18:27.9 | 1969
18:27.9 | 1966
18:27.9 | 1969
18:27.9 | 1882
18:27.9 | 1881
18:27.9 | 1880
18:27.9 | 1876
18:27.9 | 1925
18:27.9 | 1933
18:27.9 | 1902
18:27.9 | 1866
18:27.9 | 1879
18:27.9 | 1938
18:27.9 | 1958
18:27.9 | 1925
18:27.9 | 1925
18:27.9 | 1948
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

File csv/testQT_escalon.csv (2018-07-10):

col1 | col2
0 | 0
1 | 0
2 | 0
3 | 0
4 | 0
5 | 0
6 | 1
7 | 1
8 | 1
9 | 1
10 | 1
11 | 1
12 | 1
13 | 1
14 | 1
15 | 1

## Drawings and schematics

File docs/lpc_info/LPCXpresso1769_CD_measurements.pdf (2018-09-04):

# Measurements LPCXpresso1769/CD

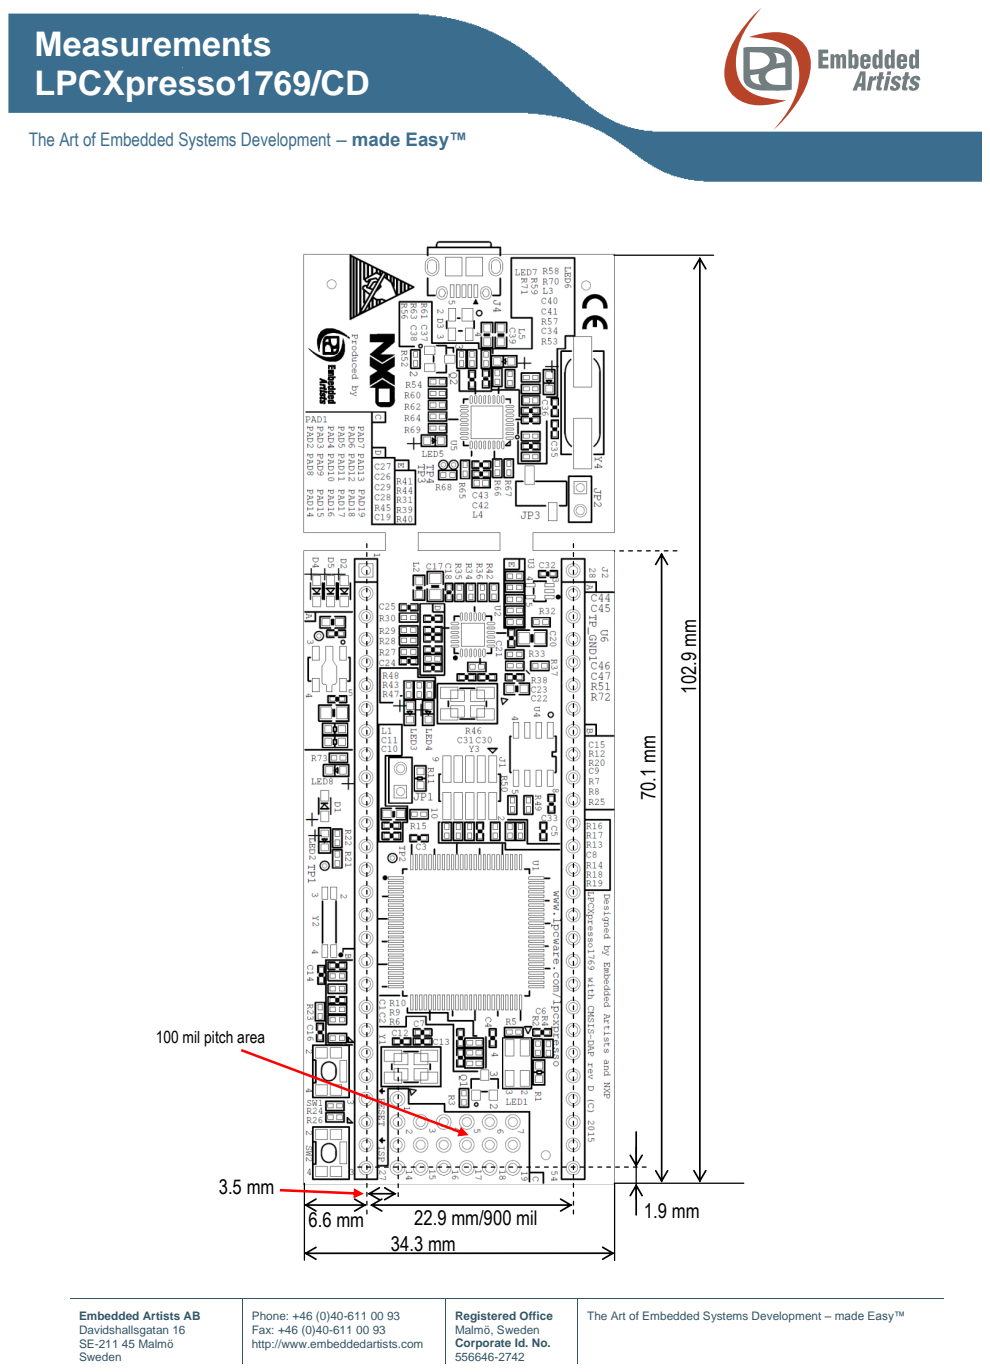
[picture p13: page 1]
22.9 mm/900 mil .6 mm

The Art of Embedded Systems Development – made Easy™

100 mil pitch area

Embedded Artists AB
Davidshallsgatan 16
SE-211 45 Malmö
Sweden

Phone: +46 (0)40-611 00 93
Fax: +46 (0)40-611 00 93
http://www.embeddedartists.com

Registered Office
Malmö, Sweden
Corporate Id. No.

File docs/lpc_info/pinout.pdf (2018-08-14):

# LPC1769 - LPCXpresso Board Consolidated Pinout Diagram

# Rohit Ramesh

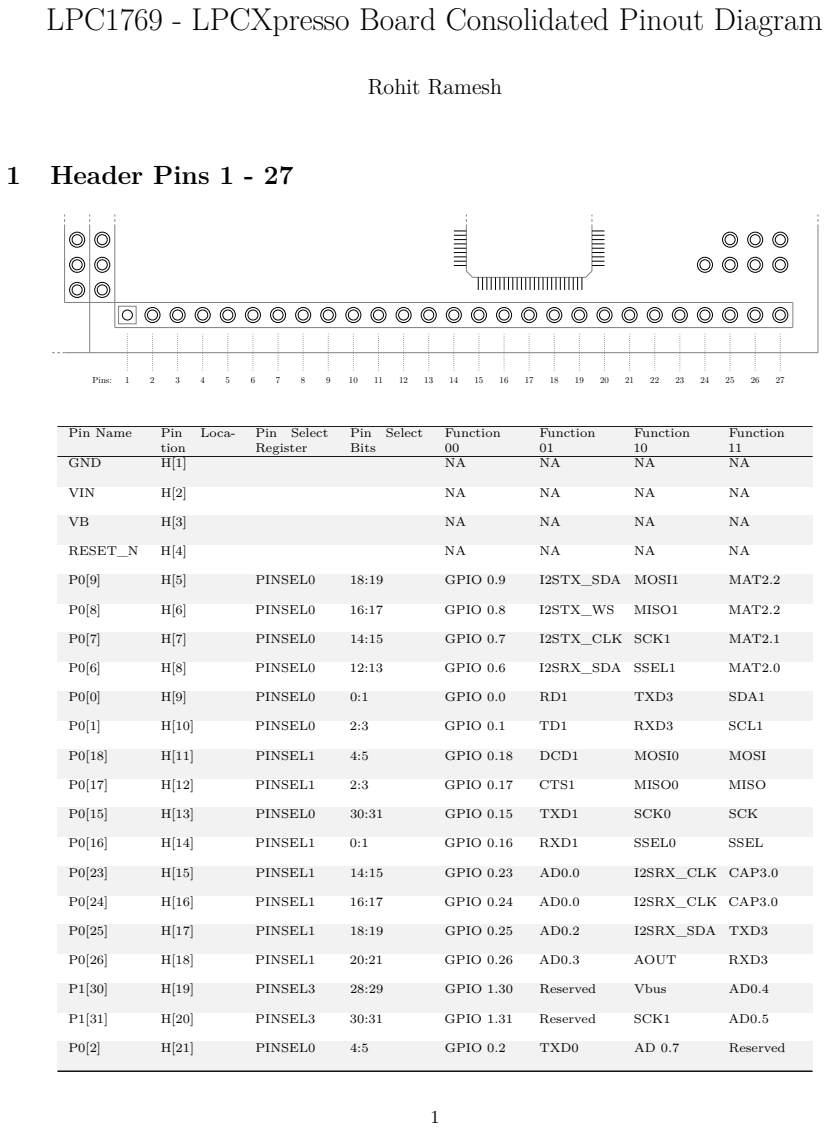
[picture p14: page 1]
1 Header Pins 1 - 27; Pins:; Pin Name; Pin; Loca-; tion; Select; Register; Bits; Function 00; Function 01; Function 10; Function 11; GND; VIN; RESET_N; PINSEL0; GPIO 0.9; I2STX_SDA MOSI1; MAT2.2; GPIO 0.8; I2STX_WS; MISO1; GPIO 0.7; I2STX_CLK SCK1; MAT2.1; GPIO 0.6; I2SRX_SDA SSEL1; MAT2.0; GPIO 0.0; TXD3; SDA1; GPIO 0.1; RXD3; SCL1; PINSEL1; GPIO 0.18; DCD1; MOSI0; MOSI; GPIO 0.17; CTS1; MISO0; MISO; GPIO 0.15; TXD1; SCK0; SCK; GPIO 0.16; RXD1; SSEL0; SSEL; GPIO 0.23; I2SRX_CLK CAP3.0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

Pin Name | Pin | Loca-
tion

Pin Select
Register

Pin Select
Bits

Function
00

Function
01

Function
10

Function
11
P0[3] | H[22] | PINSEL0 | 6:7 | GPIO 0.3 | RXD0 | AD 0.6 | Reserved
P0[21] | H[23] | PINSEL1 | 10:11 | GPIO 0.21 | RI1 | Reserved | RD1
P0[22] | H[24] | PINSEL1 | 12:13 | GPIO 0.22 | RTS1 | Reserved | TD1
P0[27] | H[25] | PINSEL1 | 22:23 | GPIO 0.27 | SDA0 | USB_SDA | Reserved
P0[28] | H[26] | PINSEL1 | 24:25 | GPIO 0.28 | SCL0 | USB_SCL | Reserved
P2[13] | H[27] | PINSEL4 | 26:27 | GPIO 2.13 | | Reserved | I2STX_SDA

2

# 2 Header Pins 28 - 54

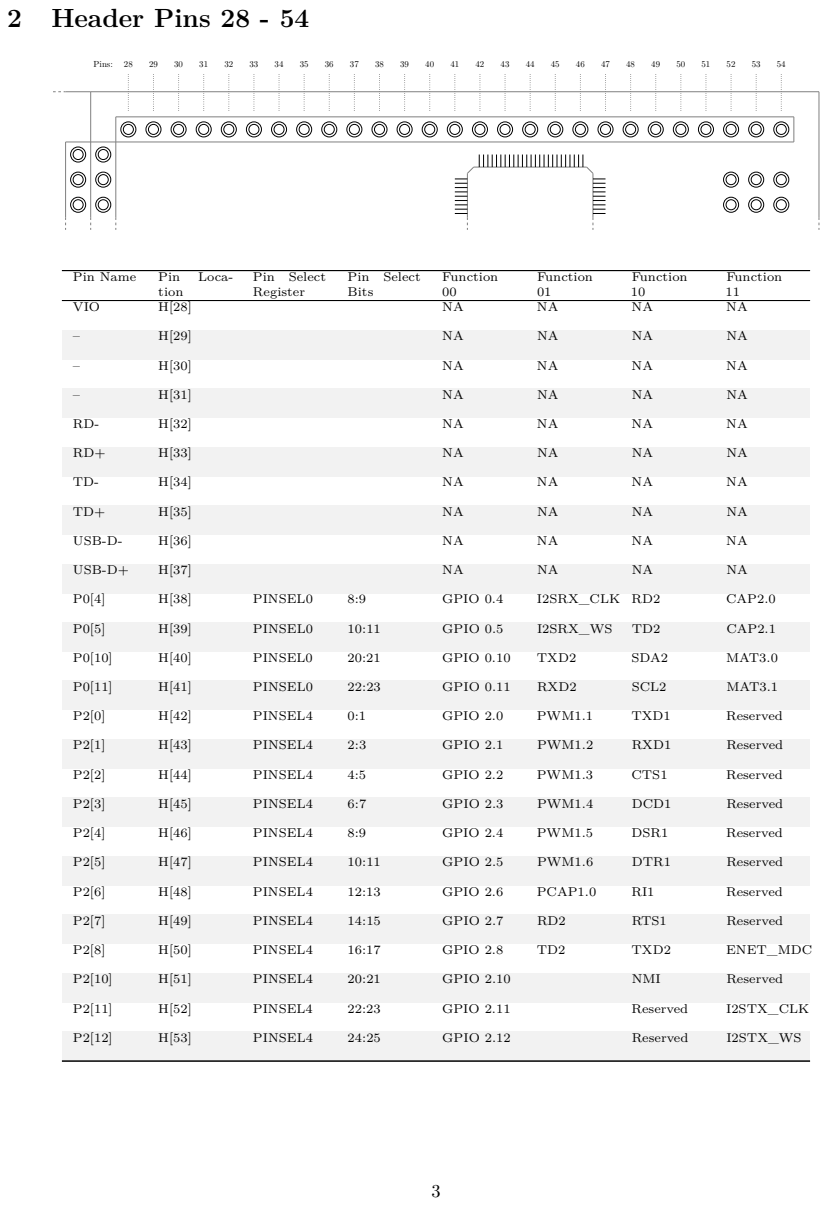
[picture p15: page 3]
Pins:; Pin Name; Pin; Loca-; tion; Select; Register; Bits; Function 00; Function 01; Function 10; Function 11; VIO; USB-D-; USB-D+; PINSEL0; GPIO 0.4; I2SRX_CLK RD2; CAP2.0; GPIO 0.5; I2SRX_WS; CAP2.1; GPIO 0.10; TXD2; SDA2; MAT3.0; GPIO 0.11; RXD2; SCL2; MAT3.1; PINSEL4; GPIO 2.0; PWM1.1; TXD1; Reserved; GPIO 2.1; PWM1.2; RXD1; GPIO 2.2; PWM1.3; CTS1; GPIO 2.3; PWM1.4; DCD1; GPIO 2.4; PWM1.5; DSR1; GPIO 2.5; PWM1.6; DTR1; GPIO 2.6; PCAP1.0; GPIO 2.7; RTS1; GPIO 2.8; ENET_MDC; GPIO 2.10; NMI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

# 3 Pad Pins 1 - 19

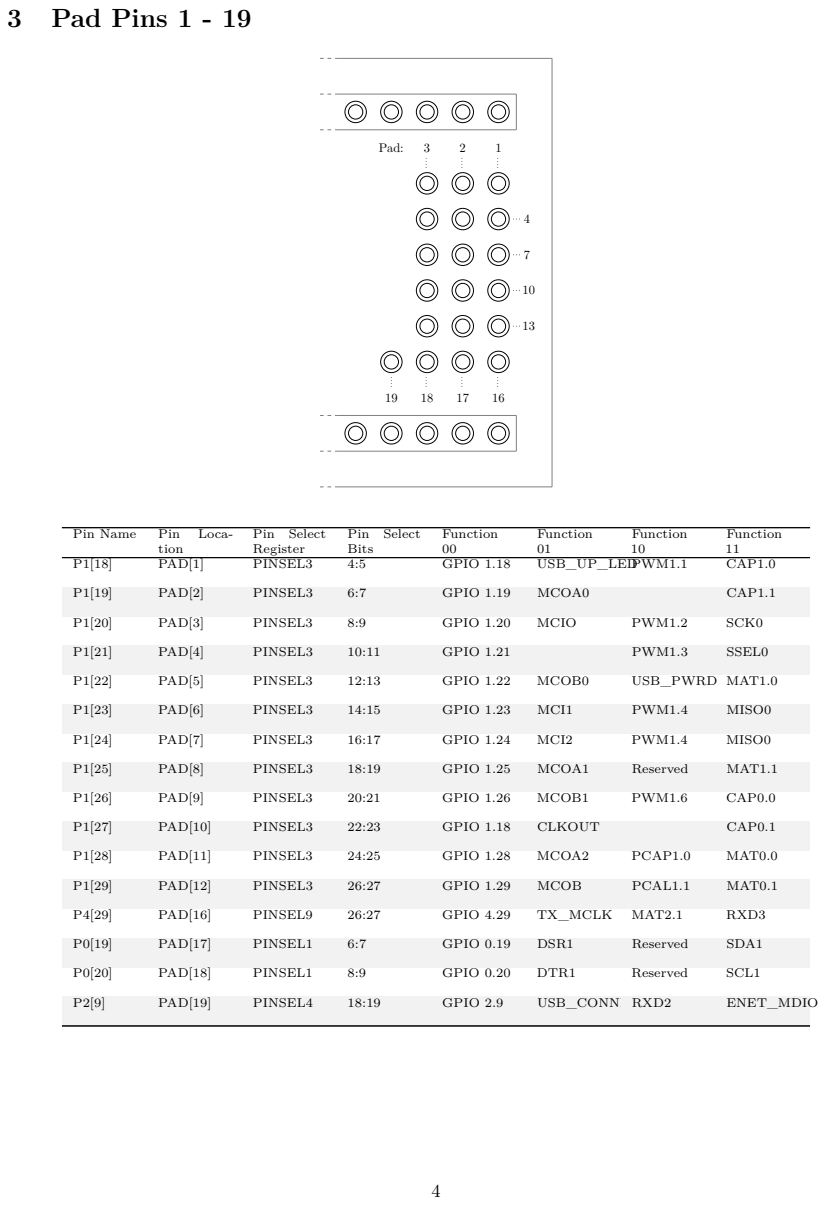
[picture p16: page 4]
Pad:; Pin Name; Pin; Loca-; tion; Select; Register; Bits; Function 00; Function 01; Function 10; Function 11; PAD[1]; PINSEL3; GPIO 1.18; USB_UP_LEDPWM1.1; CAP1.0; PAD[2]; GPIO 1.19; MCOA0; CAP1.1; PAD[3]; GPIO 1.20; MCIO; PWM1.2; SCK0; PAD[4]; GPIO 1.21; PWM1.3; SSEL0; PAD[5]; GPIO 1.22; MCOB0; USB_PWRD MAT1.0; PAD[6]; GPIO 1.23; MCI1; PWM1.4; MISO0; PAD[7]; GPIO 1.24; MCI2; PAD[8]; GPIO 1.25; MCOA1; Reserved; MAT1.1; PAD[9]; GPIO 1.26; MCOB1; PWM1.6; CAP0.0; PAD[10]; CLKOUT; CAP0.1; PAD[11]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

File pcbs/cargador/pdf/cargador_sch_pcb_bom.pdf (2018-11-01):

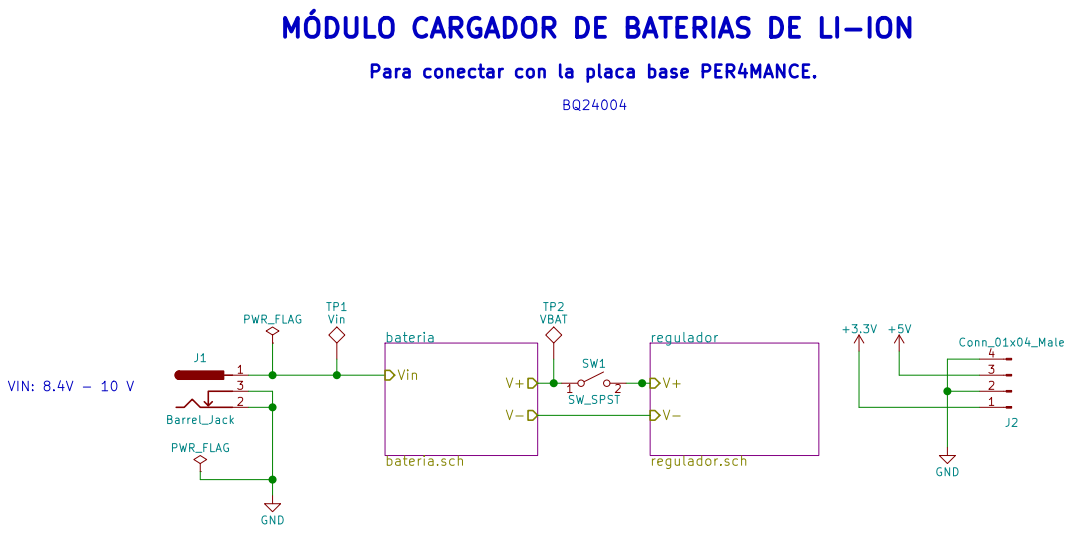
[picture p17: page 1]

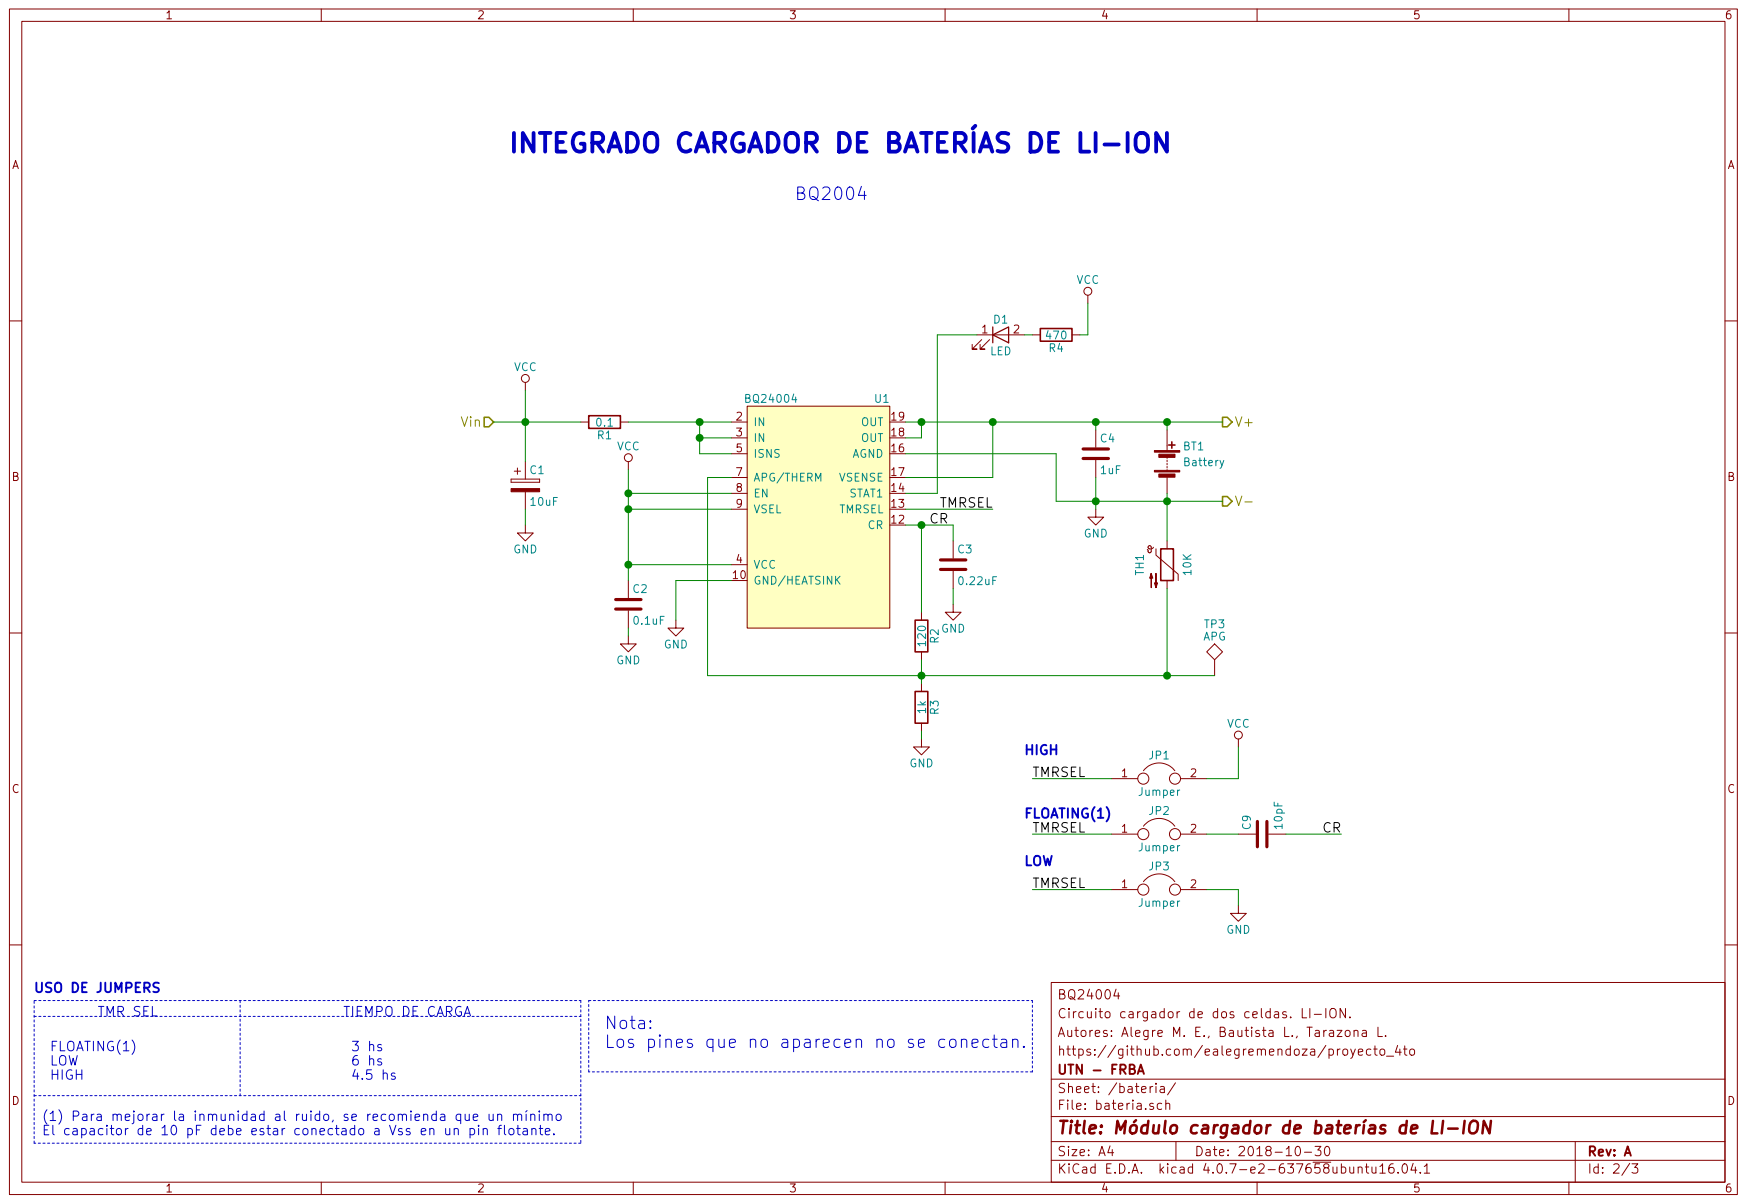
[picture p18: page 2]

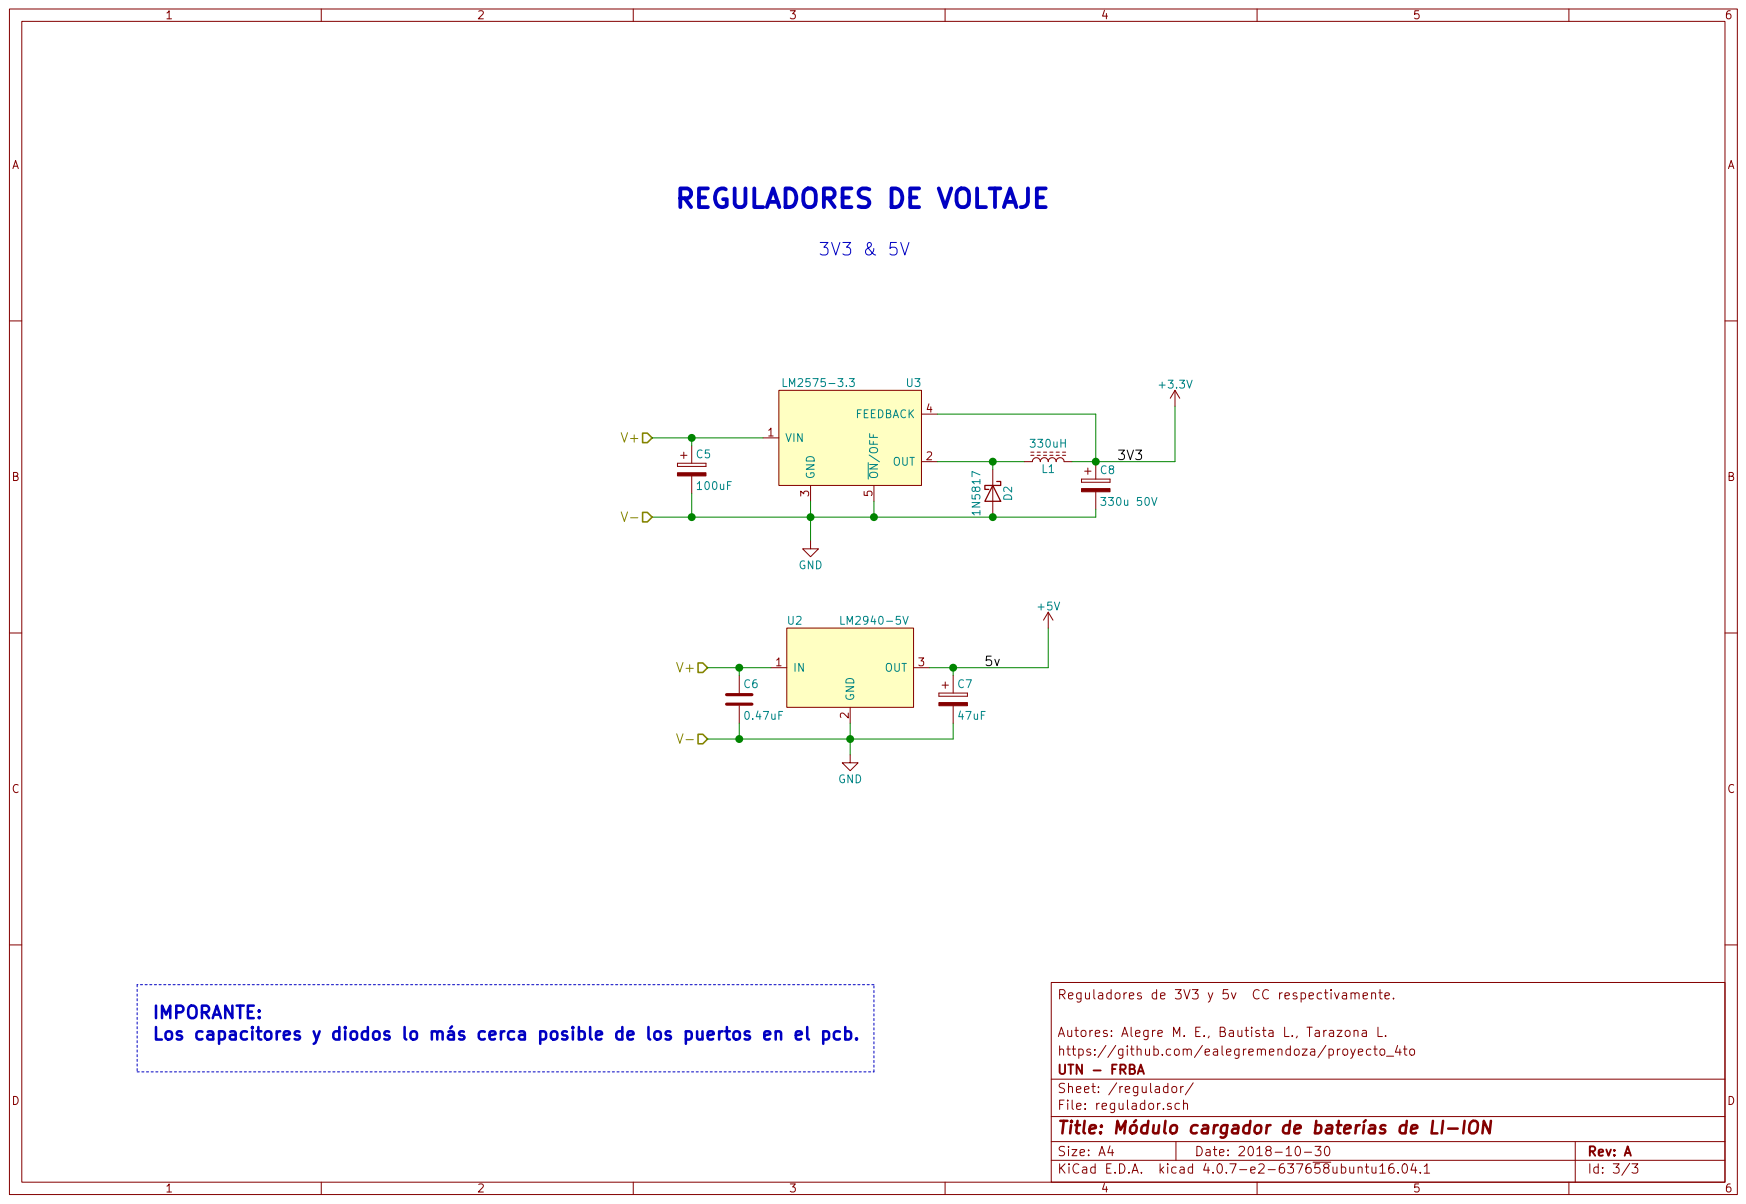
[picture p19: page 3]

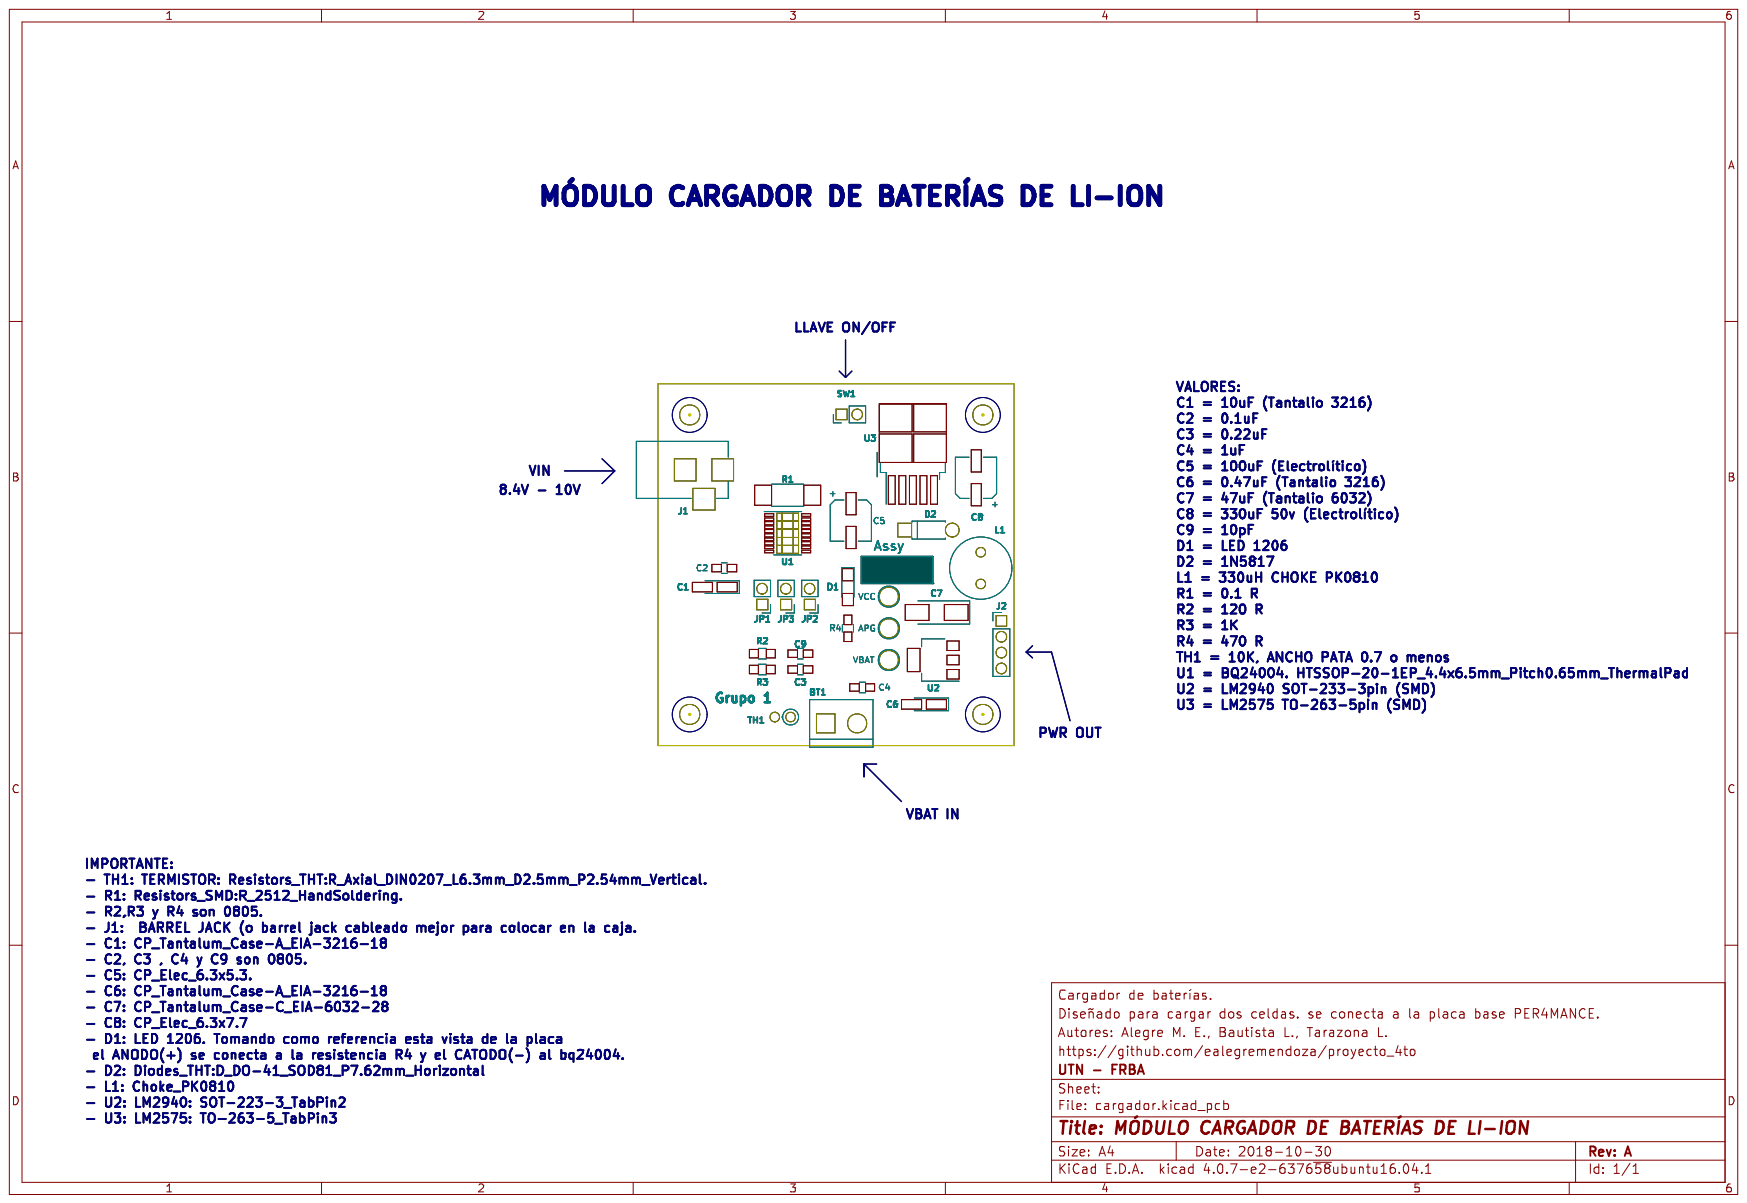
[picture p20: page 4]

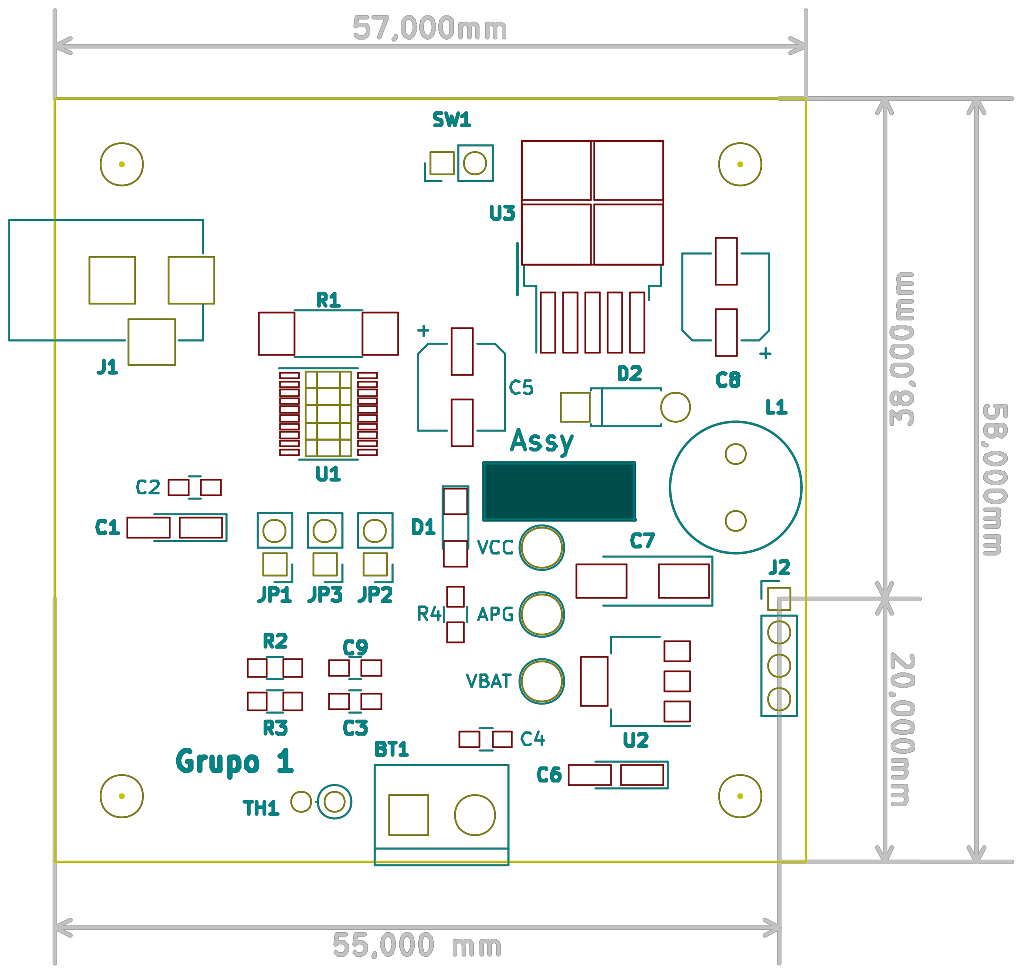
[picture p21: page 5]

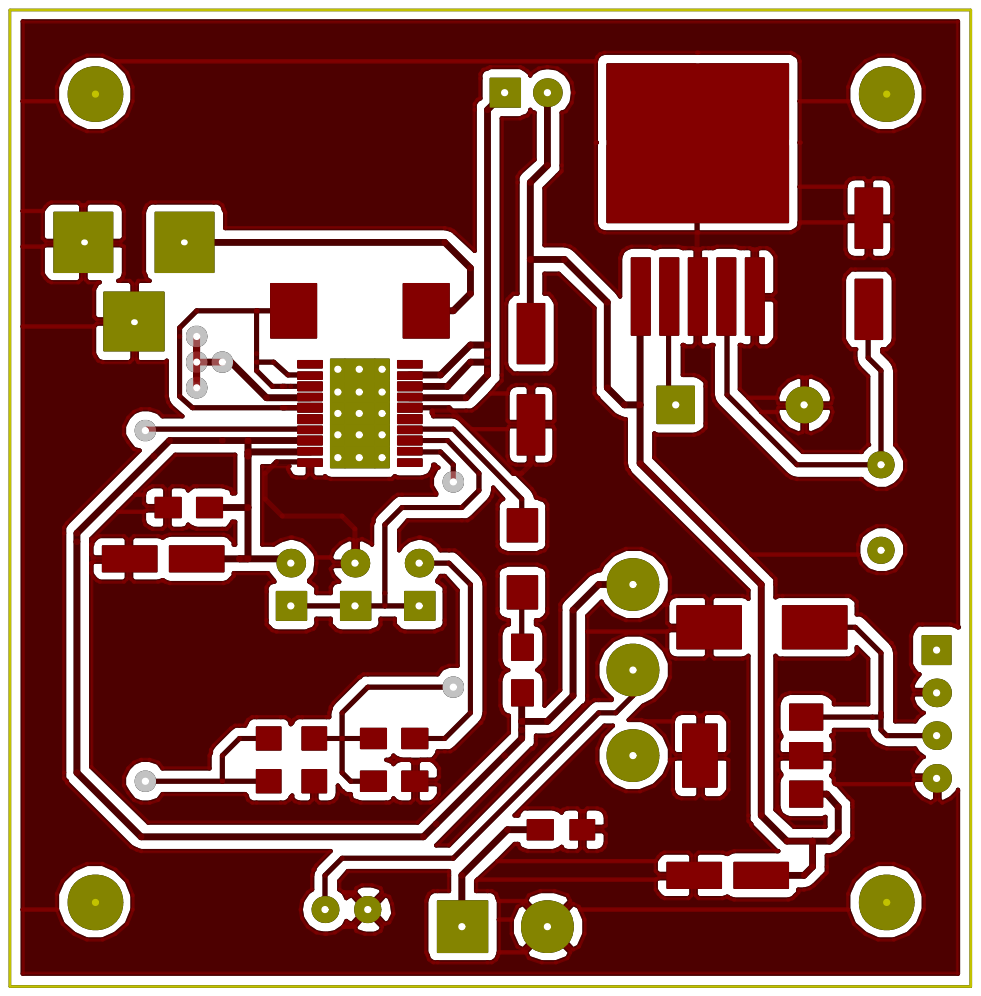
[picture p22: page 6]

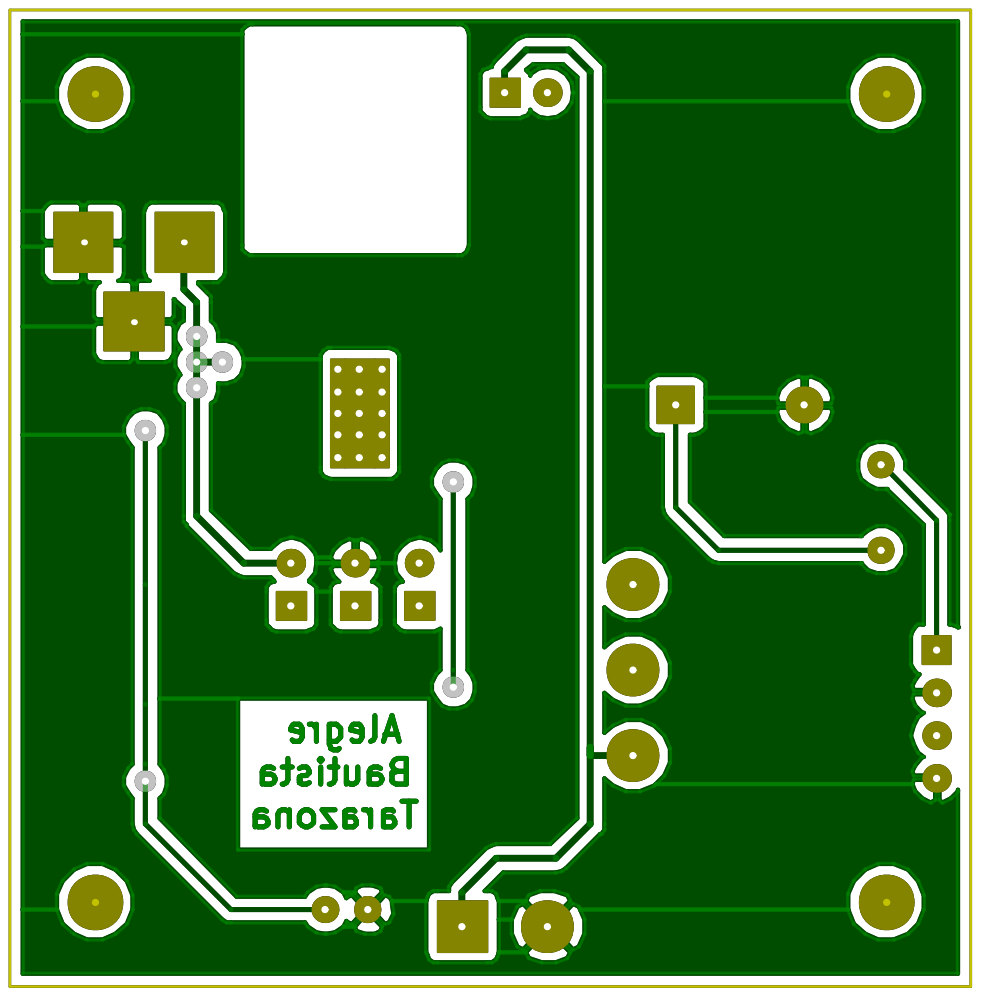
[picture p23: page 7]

cargador

Page 1

Count: | 26
Comp:
Item | Qty | Reference(s) | Value | LibPart | Footprint
| 1 BT1 | | Battery | Battery | Battery_Holders:Bulgin_BX0036_1xC
| 1 C1 | | 10uF | CP | Capacitors_Tantalum_SMD:CP_Tantalum_Case-A_EIA-3216-18_Hand
| 1 C2 | | 0.1uF | C | Capacitors_SMD:C_0805_HandSoldering
| 1 C3 | | 0.22uF | C | Capacitors_SMD:C_0805_HandSoldering
| 1 C4 | | 1uF | C | Capacitors_SMD:C_0805_HandSoldering
| 1 C5 | | 100uF | CP | Capacitors_SMD:CP_Elec_6.3x5.3
| 1 C6 | | 0.47uF | C | Capacitors_Tantalum_SMD:CP_Tantalum_Case-A_EIA-3216-18_Hand
| 1 C7 | | 47uF | CP | Capacitors_Tantalum_SMD:CP_Tantalum_Case-C_EIA-6032-28_Hand
| 1 C8 | | 330u 16V | CP | Capacitors_SMD:CP_Elec_6.3x7.7 (o sino 8x10, o sino 8x10.5)
| 1 C9 | | 10pF | C | Capacitors_SMD:C_0805_HandSoldering
| 1 D1 | | LED | LED | LEDs:LED_1206_HandSoldering
| 1 D2 | | 1N5817 | D_Schottky | Diodes_THT:D_DO-41_SOD81_P7.62mm_Horizontal
| 1 J1 | | Barrel_Jack | conn:Barrel_Jack | Connectors:BARREL_JACK
| 1 J2 | | Conn_01x04_Male | Conn_01x04_Male | Pin_Headers:Pin_Header_Straight_1x04_Pitch2.54mm
| 3 JP1, JP2, JP3 | | Jumper | Jumper | Pin_Headers:Pin_Header_Straight_1x02_Pitch2.54mm
| 1 L1 | | 330uH | L_Core_Ferrite | footprints:Choke_PK0810
| 1 R1 | | 0.1 | R | Resistors_SMD:R_2512_HandSoldering
| 1 R2 | | 120 R | | Resistors_SMD:R_0805_HandSoldering
| 1 R3 | | 1k | R | Resistors_SMD:R_0805_HandSoldering
| 1 R4 | | 470 R | | Resistors_SMD:R_0805_HandSoldering
| 1 TH1 | | 10K | Thermistor_NTC | R THT:R_Axial_DIN0207_L6.3mm_D2.5mm_P2.54mm. Ancho pata <0,8mm
| 1 U1 | | BQ24004 | bq24004:BQ24004 | Housings_SSOP:HTSSOP-20-1EP_4.4x6.5mm_Pitch0.65mm_ThermalPad
| 1 U2 | | LM2940-5V | lm2940:LM2940-5V | TO_SOT_Packages_SMD:SOT-223-3_TabPin2
| 1 U3 | | LM2575-3.3 (*) | lm2575:LM2575-3.3 | TO_SOT_Packages_SMD:TO-263-5_TabPin3
(*) De no conseguir LM2575-3.3V Un buen reemplazo es el LM2596-3.3V que tiene el mismo circuito, pero con diferentes valores de componentes.
1 U3 | LM2596-3.3V | TO-263
1 L1 | 47uH | Radial pitch 5mm THT | PK0707. CODIGO ELEMON: FI1535090
1 D1 | 1N5817 / 1N15819 / 1N5822 | D_Schottky | Axial. Cualquiera de los 3: 1N5817 / 1N15819 / 1N5822 . THT
2 C5,C8 | 330uFx16V | | Capacitors_SMD:CP_Elec_6.3x5.3 (o sino 6.3x7.7, 8x10, 8x10.5)

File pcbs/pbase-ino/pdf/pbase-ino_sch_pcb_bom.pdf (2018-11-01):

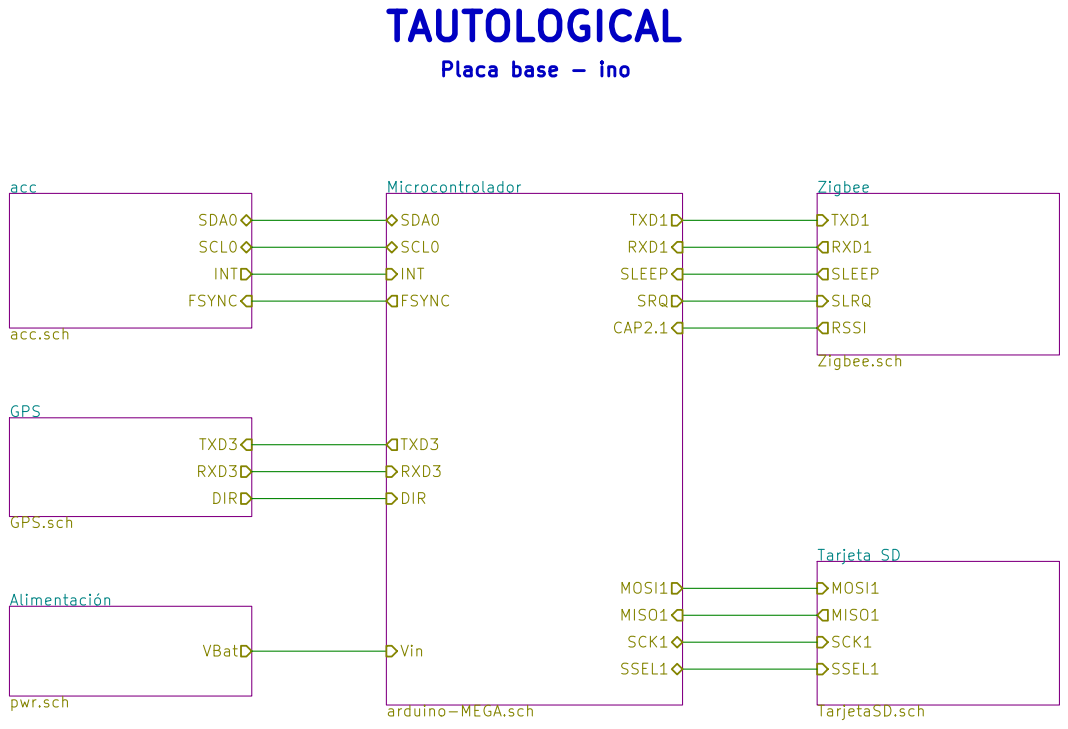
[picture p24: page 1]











pbase-ino

Page 1

Count: | 31
Item | Qty | Ref | Value | LibPart | Footprint
| 1 C1 | | 1uF x 16V | CP | C SMD:CP_Tantalum_Case-A_EIA-3216-18
| 1 C2 | | 100n | C | Capacitors_SMD:C_0805
| 1 C3 | | 100u | CP | Capacitors_SMD:CP_Elec_6.3x5.3
| 1 C4 | | 330u | CP | Capacitors_SMD:CP_Elec_10x10.5
| 1 D1 | | 1N5817 | D_Schottky | Diodes_THT:D_DO-41_SOD81_P7.62mm_Horizontal
| 1 J1 | | SD Oupiin 9004-BA09W01C00A | SD_Card CONN | SD_TE_2041021_edit
| 2 J2,SW1 | | Screw_Terminal_01x02 | BORNERA-2 P5.08mm | TerminalBlock_bornier-2_P5.08mm
| 1 L1 | | 330uH | L_Core_Ferrite | Choke_PK0810
| 1 R1 | | 0R | R | R SMD:R_0805
| 2 R2, R3 | | 10K | R | R SMD:R_0805
| 3 R4,R5,R6 | | 1K8 | R | R SMD:R_0805
| 3 R7,R8,R9 | | 3K3 | R | R SMD:R_0805
| 1 U1 | | LM2575-3.3 | lm2575:LM2575-3.3 | TO_SOT_Packages_SMD:TO-263-5_TabPin3
| 1 U3 | | GPS_EM506 | GPS_EM506 | Conn JST_SH_SM06B-SRSS-TB_06x1.00mm_Angled
| 2 | | TIRA PIN MACHO 1x40 P2.54mm | (1x26)+(1x26)+(1x10) | Para arduino MEGA y acelerómetro mpu9250
| 1 | | TIRA PIN MACHO 2X40 P2.54mm | Necesita 1 tira de 2x20 | Para arduino MEGA
| 1 | | TIRA PIN HEMBRA 2X05 P2.54mm | TIRA PIN HEMBRA 2X05 P2.54mm Para arduino MEGA
| 2 | | TIRA PIN HEMBRA 2X10 P2mm | TIRA PIN HEMBRA 2X10 P2mm | Para XBEE. Tamb pueden ser 2 tiras 1x10 P2mm
1 MOD1 | XBEE/XBEE-PRO | XBE / XBEE-PRO | xbee_xb24cz7pit_004
1 U2 | acc_mpu9250_board | acc_mpu9250_board | mpu9250_board
1 | GPS_EM506 | gps em506 | gps em506
1 XA1 | Arduino_Mega2560_Shield | arduino:Arduino_Mega2560_Shield | Arduino_Mega2560_Shield_flippedONtop

(*) De no conseguir LM2575-3.3V Un buen reemplazo es el LM2596-3.3V que tiene el mismo circuito, pero con diferentes valores de componentes.
1 U3 | LM2596-3.3V | TO-263
1 L1 | 47uH | Radial pitch 5mm THT | PK0707. CODIGO ELEMON: FI1535090
1 D1 | 1N5817 / 1N15819 / 1N5822 | D_Schottky | Axial. Cualquiera de los 3: 1N5817 / 1N15819 / 1N5822 . THT
2 C5,C8 | 330uFx16V | | Capacitors_SMD:CP_Elec_6.3x5.3 (o sino 6.3x7.7, 8x10, 8x10.5)

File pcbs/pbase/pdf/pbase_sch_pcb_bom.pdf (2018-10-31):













pbase

Page 1

Count: | 22
Comp:
Item | Qty | Ref | Value | LibPart | Footprint
| 1 C1 | | 1uF x 16V | CP | C SMD:CP_Tantalum_Case-A_EIA-3216-18_Hand
| 1 C2 | | 100n | C | C SMD:C_0805_HandSoldering
| 1 J1 | | SD Oupiin 9004-BA09W01C00A | conn:SD_Card | SD_TE_2041021_edit
| 1 R1 | | 0R | R | R SMD:R_0805_HandSoldering
| 2 R2, R3 | | 10K | R | R SMD:R_0805_HandSoldering
| 2 R4, R5 | | 33K | R | R SMD:R_0805_HandSoldering
| 1 R6 | | RD1 | R | R SMD:R_0805_HandSoldering
| 1 R7 | | RD2 | R | R SMD:R_0805_HandSoldering
| 1 U3 | | GPS_EM506 | GPS_EM506 | Conn JST_SH_SM06B-SRSS-TB_06x1.00mm_Angled
| 2 | | Conn_02x10 | PINES HEMBRA 2X10 p2mm | Para el zigbee. Si no se consigue ? 2 TIRAS PINES HEMBRA 1X10
| 2 | | PINES HEMBRA 1X40 P2.54mm | PINES HEMBRA 1X40 P2.54mm | Para lpc1769,acelerómetro, PWR y display.
1 U1 | LPCXpresso_LPC1769_revc | LPCXpresso_LPC1769_revc | lpc1769_board_revC
1 U2 | acc_mpu9250_board | acc_mpu9250_board | mpu9250_board
1 U3.1 | GPS_EM506 | GPS_EM506 | GPS EM506
1 MOD1 | XB24CZ7PIT-004 | XBEE / XBEE-PRO | xbee_xb24cz7pit_004

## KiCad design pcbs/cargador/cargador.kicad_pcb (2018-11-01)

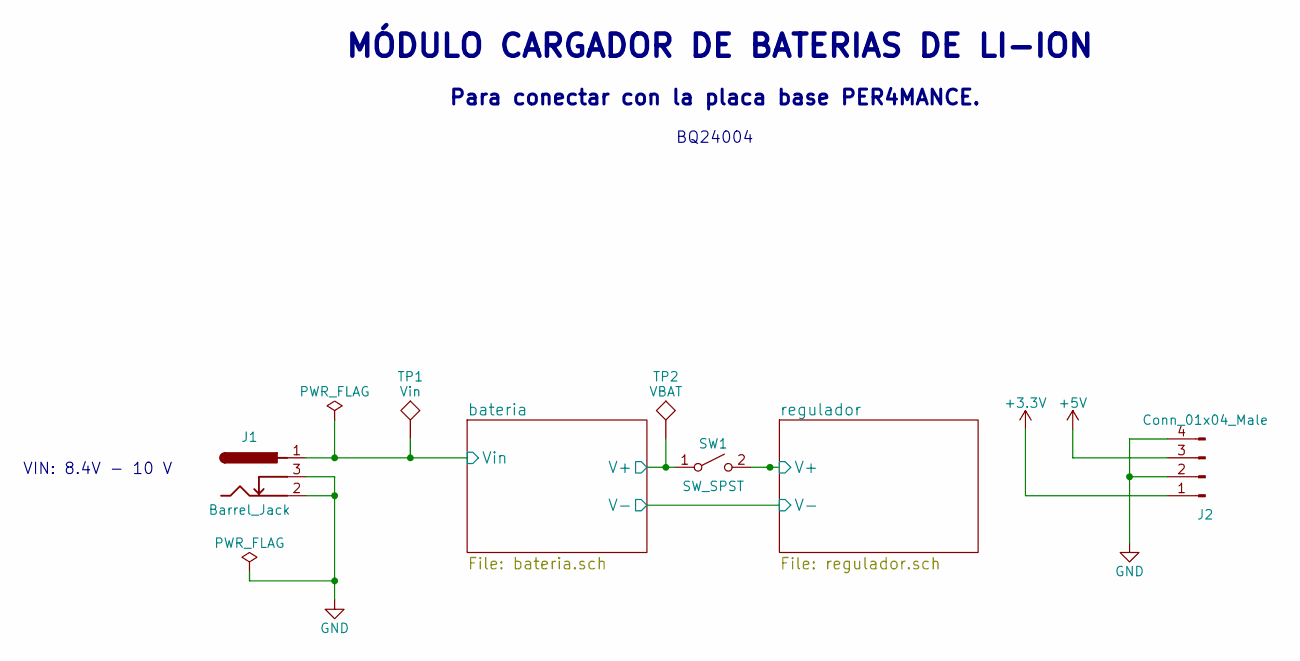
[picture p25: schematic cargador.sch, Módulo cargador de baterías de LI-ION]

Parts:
J1: Barrel_Jack; BARREL_JACK
J2: Conn_01x04_Male; Pin_Header_Straight_1x04_Pitch2.54mm
SW1: SW_SPST; Pin_Header_Straight_1x02_Pitch2.54mm
TP1: Vin; TestPoint_Plated_Hole_D2.0mm
TP2: VBAT; TestPoint_Plated_Hole_D2.0mm

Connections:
+3V3: J2.1; also elsewhere on the board
+5V: J2.3; also elsewhere on the board
/bateria/V+: SW1.1 (A), TP2.1; also elsewhere on the board
/regulador/V+: SW1.2 (B); also elsewhere on the board
GND: J1.2, J1.3, J2.2, J2.4; also elsewhere on the board
VCC: J1.1, TP1.1; also elsewhere on the board

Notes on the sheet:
MÓDULO CARGADOR DE BATERIAS DE LI-ION
BQ24004
Para conectar con la placa base PER4MANCE.
VIN: 8.4V - 10 V

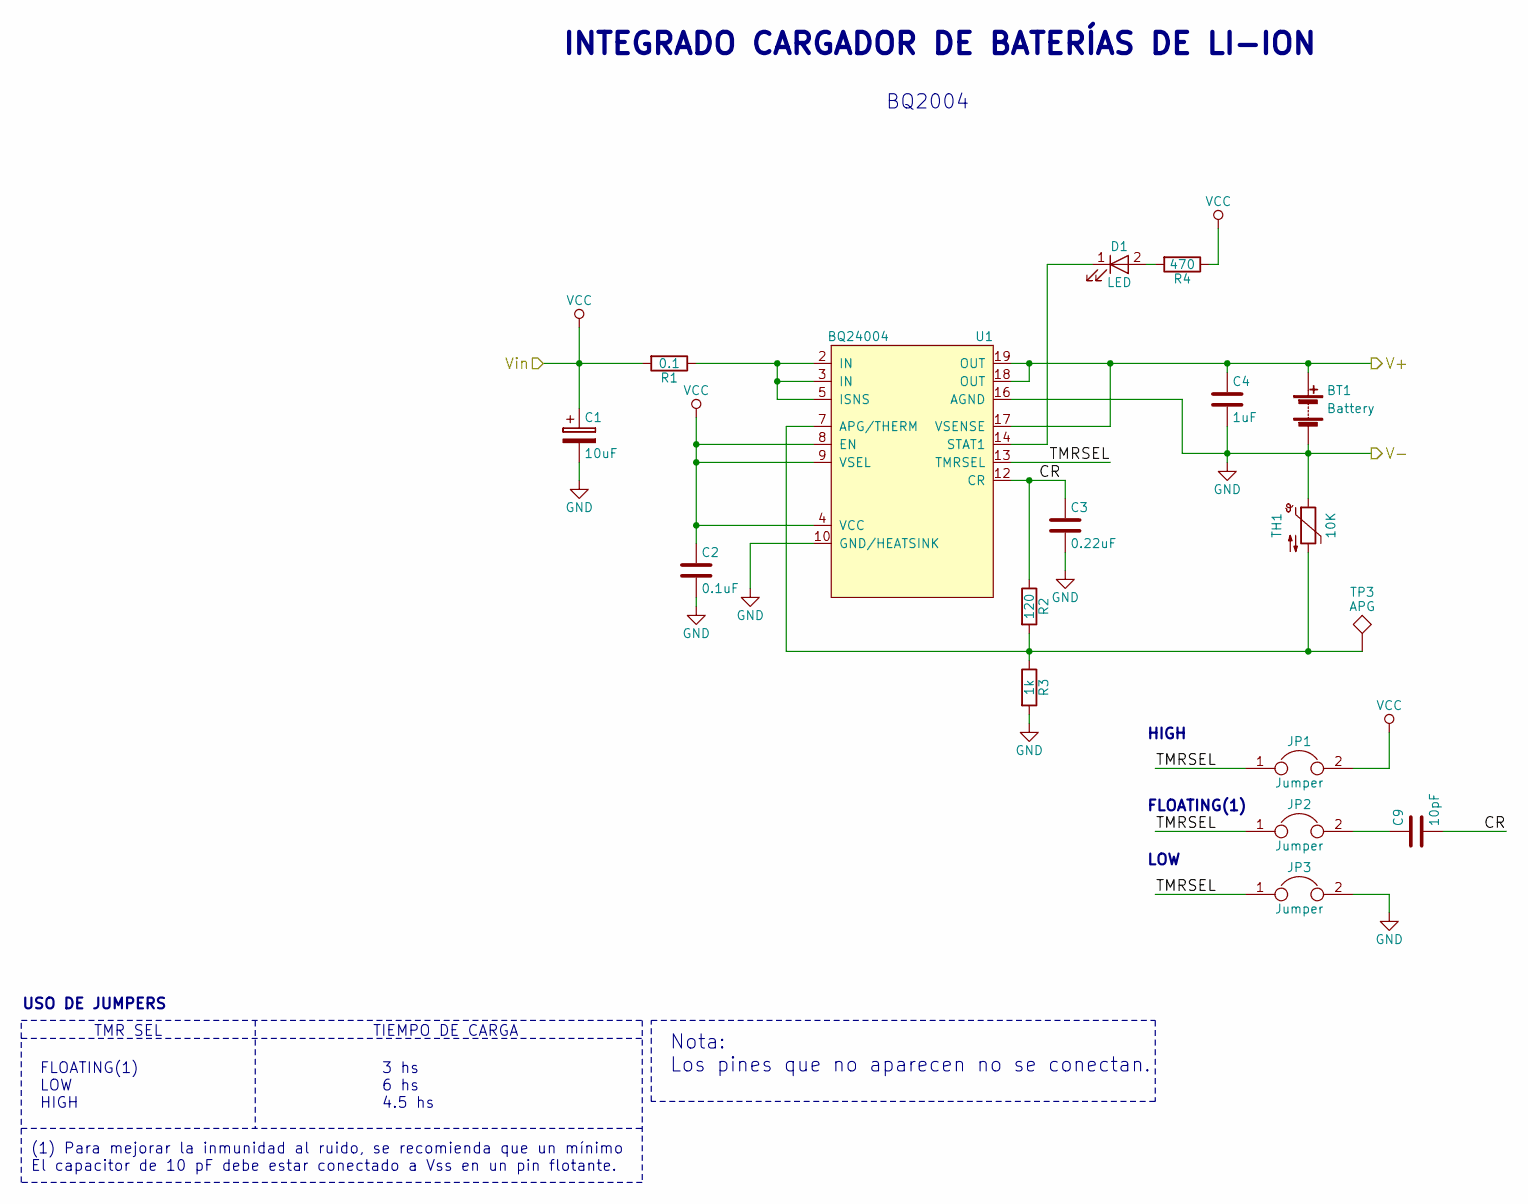
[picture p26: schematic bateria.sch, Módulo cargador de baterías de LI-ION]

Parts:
BT1: Battery; TerminalBlock_bornier-2_P5.08mm
C1: 10uF; CP_Tantalum_Case-A_EIA-3216-18_Hand
C2: 0.1uF; C_0805_HandSoldering
C3: 0.22uF; C_0805_HandSoldering
C4: 1uF; C_0805_HandSoldering
C9: 10pF; C_0805_HandSoldering
D1: LED; LED_1206_HandSoldering
JP1, JP2, JP3: Jumper; Pin_Header_Straight_1x02_Pitch2.54mm
R1: 0.1; R_2512_HandSoldering
R2: 120; R_0805_HandSoldering
R3: 1k; R_0805_HandSoldering
R4: 470; R_0805_HandSoldering
TH1: 10K; R_Axial_DIN0207_L6.3mm_D2.5mm_P2.54mm_Vertical
TP3: APG; TestPoint_Plated_Hole_D2.0mm
U1: BQ24004; HTSSOP-20-1EP_4.4x6.5mm_Pitch0.65mm_ThermalPad

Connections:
/bateria/CR: C3.1, C9.2, R2.1, U1.12 (CR)
/bateria/TMRSEL: JP1.1, JP2.1, JP3.1, U1.13 (TMRSEL)
/bateria/V+: BT1.1 (+), C4.1, U1.17 (VSENSE), U1.18 (OUT), U1.19 (OUT); also elsewhere on the board
GND: BT1.2 (-), C1.2, C2.2, C3.2, C4.2, JP3.2, R3.2, TH1.1, U1.10 (GND/HEATSINK), U1.16 (AGND); also elsewhere on the board
unnamed: C9.1, JP2.2
unnamed: D1.1 (K), U1.14 (STAT1)
unnamed: D1.2 (A), R4.2
unnamed: R1.1, U1.2 (IN), U1.3 (IN), U1.5 (ISNS)
unnamed 12: R2.2, R3.1, TH1.2, TP3.1, U1.7 (APG/THERM); also elsewhere on the board
VCC: C1.1, C2.1, JP1.2, R1.2, R4.1, U1.4 (VCC), U1.8 (EN), U1.9 (VSEL); also elsewhere on the board

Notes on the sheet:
INTEGRADO CARGADOR DE BATERÍAS DE LI-ION
BQ2004
Nota: Los pines que no aparecen no se conectan.
FLOATING(1) LOW HIGH
3 hs 6 hs 4.5 hs
TMR SEL
TIEMPO DE CARGA
(1) Para mejorar la inmunidad al ruido, se recomienda que un mínimo El capacitor de 10 pF debe estar conectado a Vss en un pin flotante.
USO DE JUMPERS
HIGH
FLOATING(1)
LOW

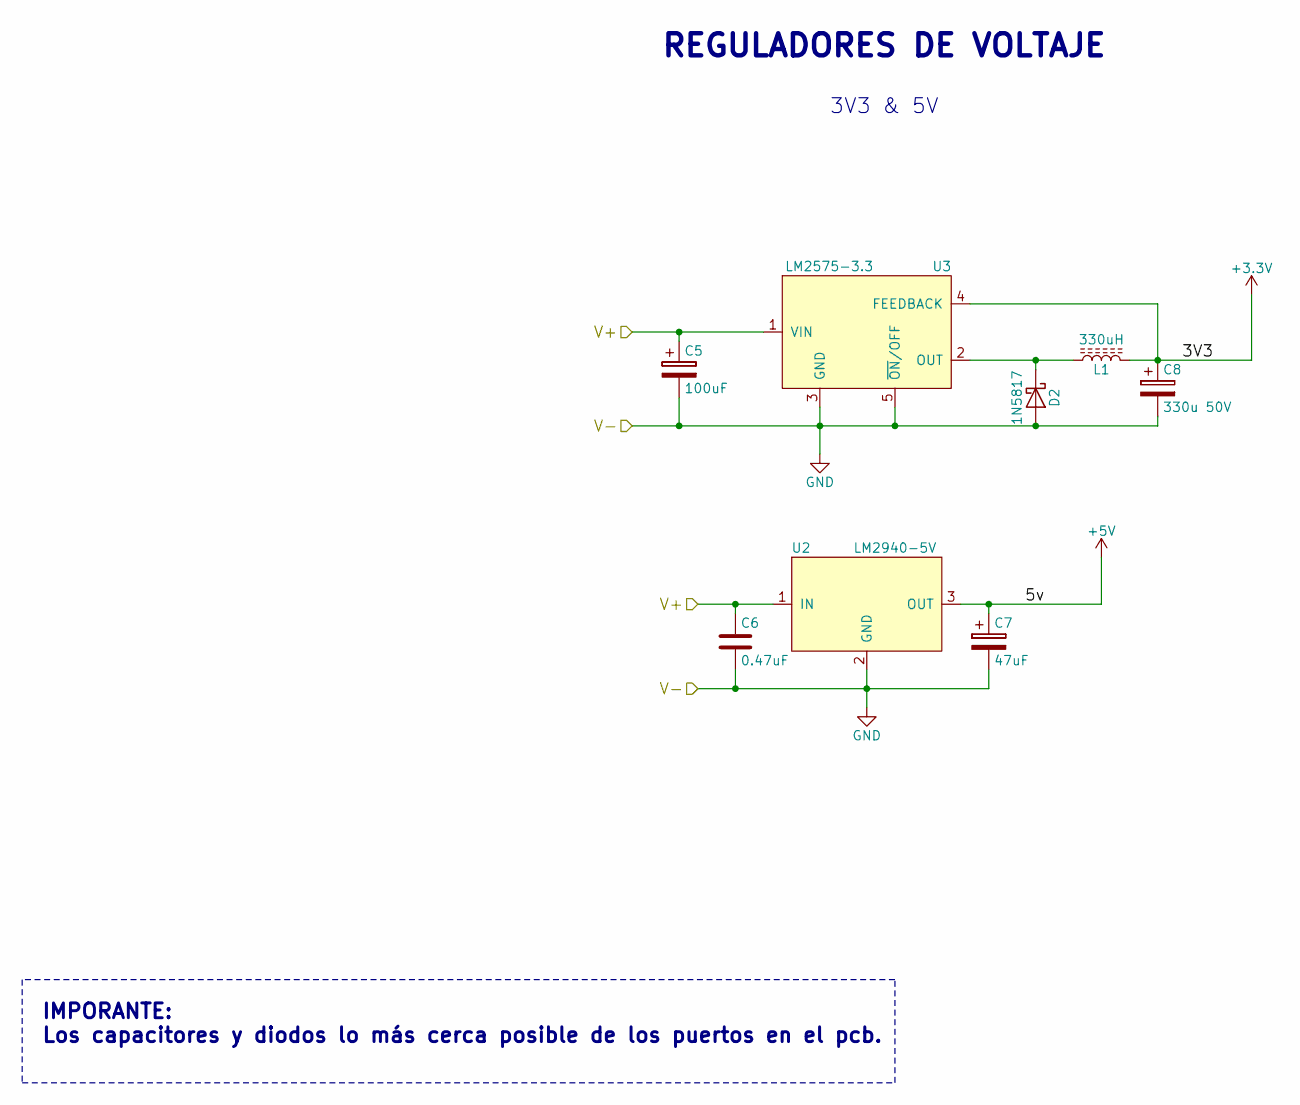
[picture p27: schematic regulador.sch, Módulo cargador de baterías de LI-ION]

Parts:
C5: 100uF; CP_Elec_6.3x5.3
C6: 0.47uF; CP_Tantalum_Case-A_EIA-3216-18_Hand
C7: 47uF; CP_Tantalum_Case-C_EIA-6032-28_Hand
C8: 330u 50V; CP_Elec_6.3x7.7
D2: 1N5817; D_DO-41_SOD81_P7.62mm_Horizontal
L1: 330uH; Choke_PK0810
U2: LM2940-5V; SOT-223-3_TabPin2
U3: LM2575-3.3; TO-263-5_TabPin3

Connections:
+3V3: C8.1, L1.2, U3.4 (FEEDBACK); also elsewhere on the board
+5V: C7.1, U2.3 (OUT); also elsewhere on the board
/regulador/V+: C5.1, C6.1, U2.1 (IN), U3.1 (VIN); also elsewhere on the board
GND: C5.2, C6.2, C7.2, C8.2, D2.2 (A), U2.2 (GND), U3.3 (GND), U3.5 (~ON~/OFF); also elsewhere on the board
unnamed: D2.1 (K), L1.1, U3.2 (OUT)

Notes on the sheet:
REGULADORES DE VOLTAJE
3V3 & 5V
IMPORANTE: Los capacitores y diodos lo más cerca posible de los puertos en el pcb.

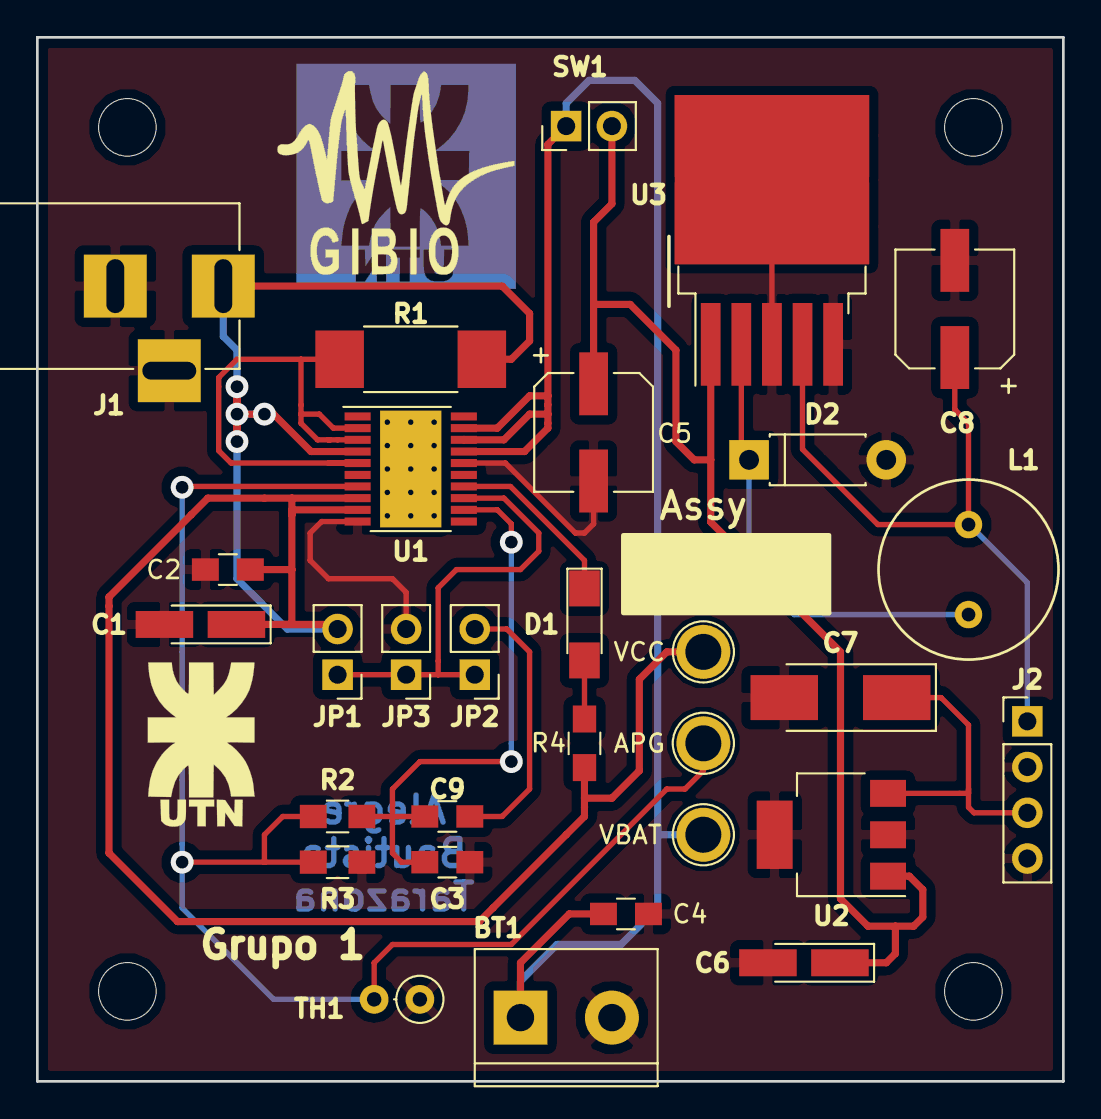
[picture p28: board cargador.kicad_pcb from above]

Board: 2 copper layers, 57.0 x 58.0 mm, 38 parts (1 on the bottom side), 14 nets.

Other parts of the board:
 : logoUTN1
  : MountingHole_3.2mm_M3_DIN965
  #2: MountingHole_3.2mm_M3_DIN965
 #2,  #3: MountingHole_3.2mm_M3_DIN965
 #4: logoGIBIO
 #5: logoGIBIO5
 #6: logoUTN3
APG: APG; TestPoint_Plated_Hole_D2.0mm
VBAT: VBAT; TestPoint_Plated_Hole_D2.0mm
VCC: Vin; TestPoint_Plated_Hole_D2.0mm

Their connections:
/bateria/V+: VBAT.1; also elsewhere on the board
unnamed 12: APG.1; also elsewhere on the board
VCC: VCC.1; also elsewhere on the board

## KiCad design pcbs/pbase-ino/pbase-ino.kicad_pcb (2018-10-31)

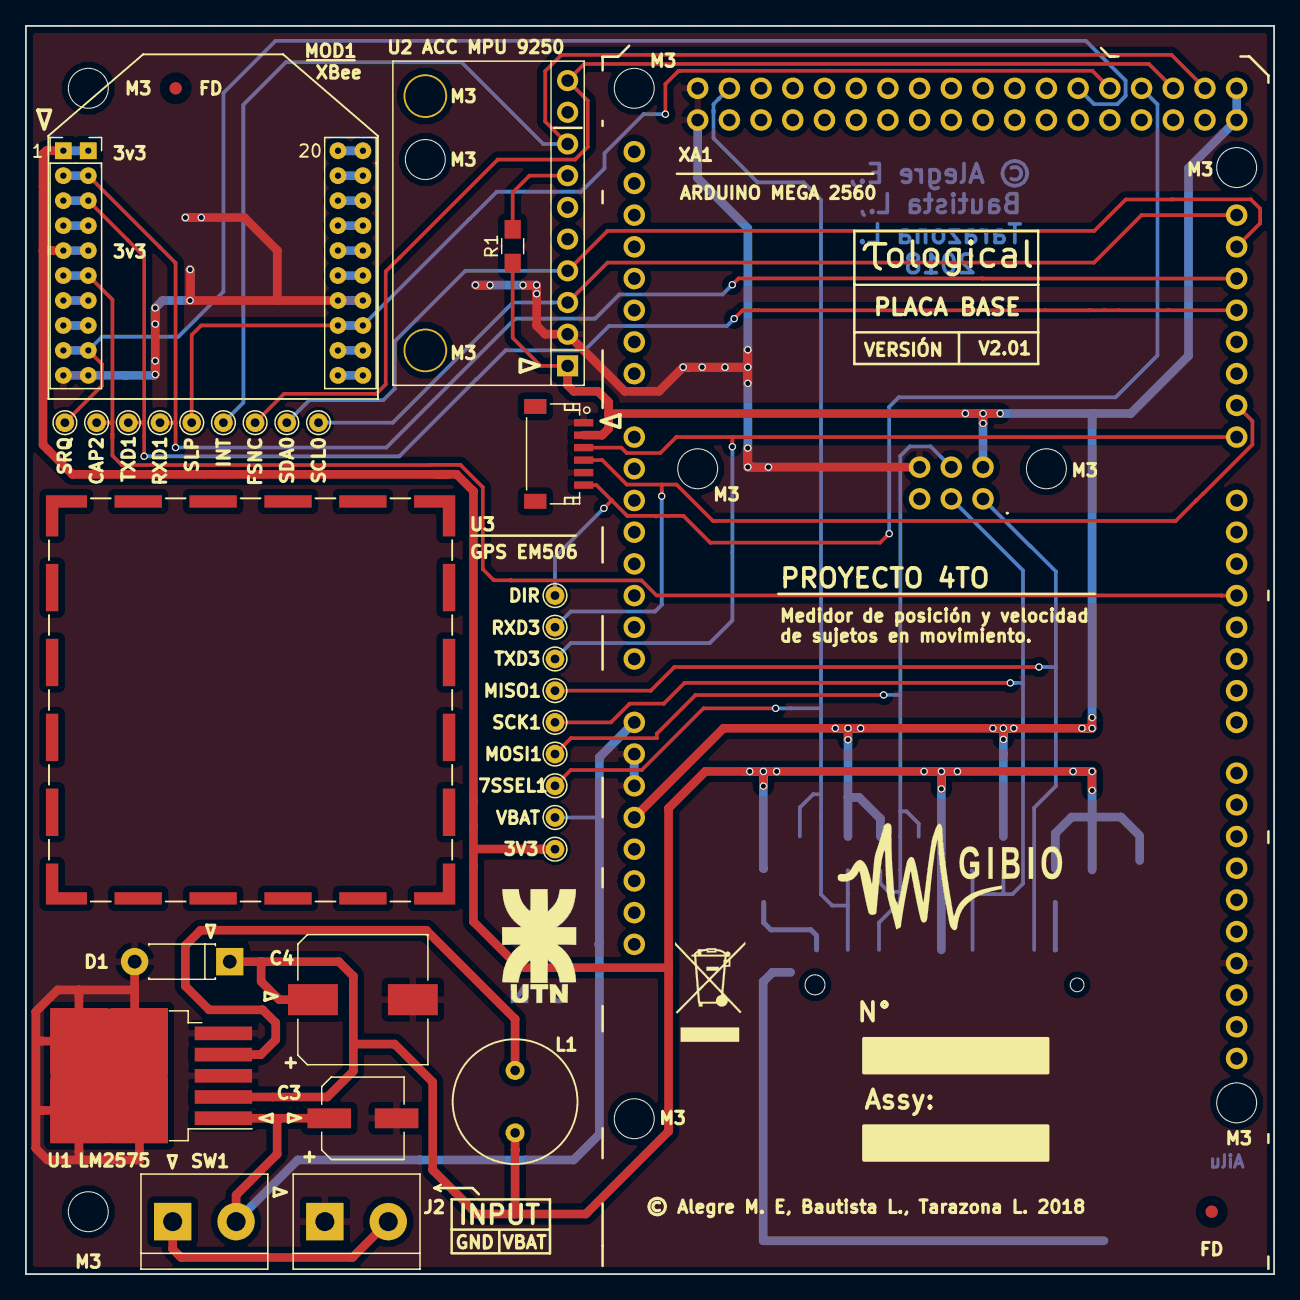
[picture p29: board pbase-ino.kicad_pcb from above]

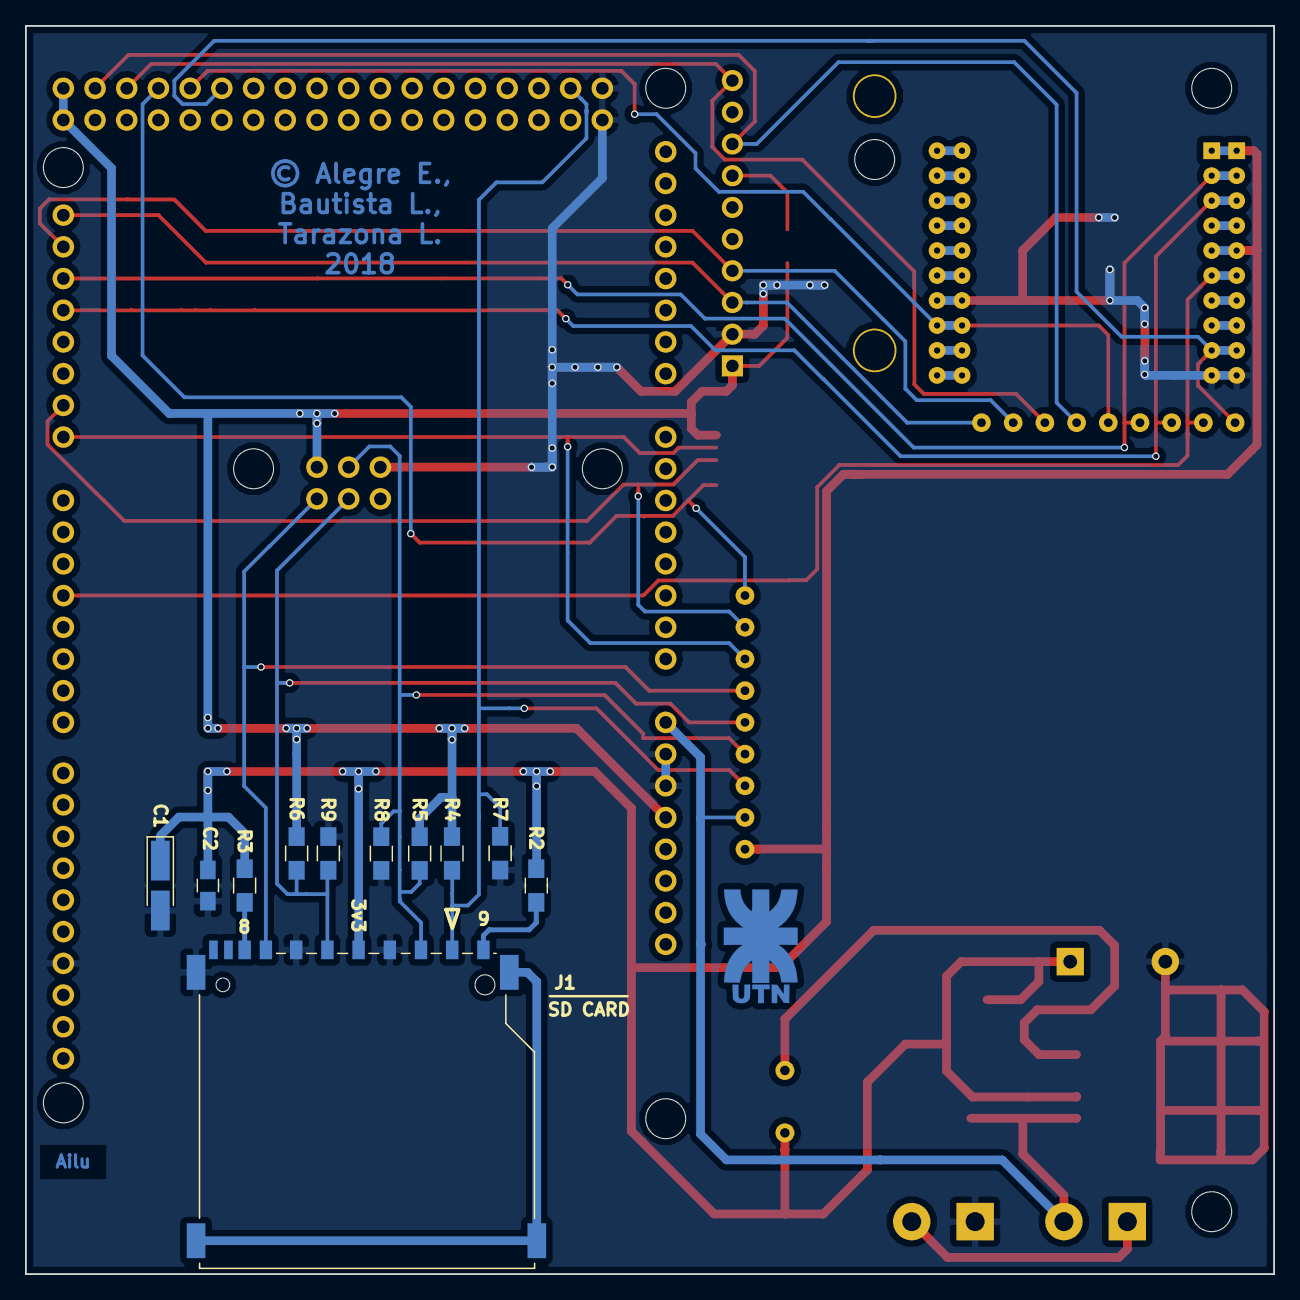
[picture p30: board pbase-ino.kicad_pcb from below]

Board: 2 copper layers, 100.0 x 100.0 mm, 47 parts (12 on the bottom side), 25 nets.

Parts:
C1: 1uF x 16V; CP_Tantalum_Case-A_EIA-3216-18_Hand
C2: 100n; C_0805_HandSoldering
C3: 100u; CP_Elec_6.3x5.3
C4: 330u; CP_Elec_10x10.5
D1: 1N5817; D_DO-41_SOD81_P7.62mm_Horizontal
FD: Fiducial_1mm_Dia_2.54mm_Outer_CopperTop
FD#2: Fiducial_1mm_Dia_2.54mm_Outer_CopperTop
GPS EM506: Laird_Technologies_BMI-S-204-F_32.00x32.00mm
J1: SD_Card; SD_TE_2041021_edit
J2: Screw_Terminal_01x02; TerminalBlock_bornier-2_P5.08mm
L1: L_Core_Ferrite; Choke_PK0810
M3, M3#2, M3#3: MountingHole_3.2mm_M3_DIN965
MOD1: XB24CZ7PIT-004; xbee_xb24cz7pit_004
R1: 0R; R_0805_HandSoldering
R2, R3: 10K; R_0805_HandSoldering
R4: r4; R_0805_HandSoldering
R5: r5; R_0805_HandSoldering
R6: r6; R_0805_HandSoldering
R7: r7; R_0805_HandSoldering
R8: r8; R_0805_HandSoldering
R9: r9; R_0805_HandSoldering
SW1: SW_SPST; TerminalBlock_bornier-2_P5.08mm
TP1: SDA0; TestPoint_THTPad_D1.5mm_Drill0.7mm
TP2: SCL0; TestPoint_THTPad_D1.5mm_Drill0.7mm
TP3: INT; TestPoint_THTPad_D1.5mm_Drill0.7mm
TP4: FSNC; TestPoint_THTPad_D1.5mm_Drill0.7mm
TP5: TXD3; TestPoint_THTPad_D1.5mm_Drill0.7mm
TP6: RXD3; TestPoint_THTPad_D1.5mm_Drill0.7mm
TP7: DIR; TestPoint_THTPad_D1.5mm_Drill0.7mm
TP8: RXD1; TestPoint_THTPad_D1.5mm_Drill0.7mm
TP9: TXD1; TestPoint_THTPad_D1.5mm_Drill0.7mm
TP10: SLP; TestPoint_THTPad_D1.5mm_Drill0.7mm
TP11: SRQ; TestPoint_THTPad_D1.5mm_Drill0.7mm
TP12: CAP2; TestPoint_THTPad_D1.5mm_Drill0.7mm
TP13: MOSI1; TestPoint_THTPad_D1.5mm_Drill0.7mm
TP14: MISO1; TestPoint_THTPad_D1.5mm_Drill0.7mm
TP15: SCK1; TestPoint_THTPad_D1.5mm_Drill0.7mm
TP16: 7SSEL1; TestPoint_THTPad_D1.5mm_Drill0.7mm
TP21: VBAT; TestPoint_THTPad_D1.5mm_Drill0.7mm
TP22: 3V3; TestPoint_THTPad_D1.5mm_Drill0.7mm
U1: LM2575-3.3; TO-263-5_TabPin3
U2: acc_mpu9250_board; mpu9250_board
U3: GPS_EM506; JST_SH_SM06B-SRSS-TB_06x1.00mm_Angled
XA1: Arduino_Mega2560_Shield; Arduino_Mega2560_Shield_flippedONtop

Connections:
+3V3: C1.1, C2.1, C4.1, D1.1, J1.4, L1.2, MOD1.1, MOD1.5, R2.1, R3.1, TP22.1, U1.2
+5V: R1.1, R4.1, R5.1, R6.1, U2.1, U3.2, XA1.5V1, XA1.5V2, XA1.5V3, XA1.5V4
/Alimentación/VBat: C3.1, SW1.2, TP21.1, U1.1, XA1.VIN
/GPS/DIR: TP7.1, U3.6, XA1.D27
/GPS/RXD3: TP6.1, U3.4, XA1.D15
/GPS/TXD3: TP5.1, U3.3, XA1.D14
/Microcontrolador/CAP2.1: MOD1.6, TP12.1, XA1.D3
/Microcontrolador/FSYNC: TP4.1, U2.10, XA1.D25
/Microcontrolador/INT: TP3.1, U2.8, XA1.D23
/Microcontrolador/MISO1: J1.7, TP14.1, XA1.MISO
/Microcontrolador/MOSI1: J1.2, R5.2, R8.1, TP13.1, XA1.MOSI
/Microcontrolador/RXD1: MOD1.2, TP8.1, XA1.D19
/Microcontrolador/SCK1: J1.5, R6.2, R9.1, TP15.1, XA1.SCK
/Microcontrolador/SCL0: TP2.1, U2.3, XA1.D21
/Microcontrolador/SDA0: TP1.1, U2.4, XA1.D20
/Microcontrolador/SLEEP: MOD1.13, TP10.1, XA1.D29
/Microcontrolador/SSEL1: J1.1, R4.2, R7.1, TP16.1, XA1.D53
/Microcontrolador/TXD1: MOD1.3, TP9.1, XA1.D18
/Tarjeta SD/data1: J1.8, R3.2
/Tarjeta SD/data2: J1.9, R2.2
/Zigbee/SLRQ: MOD1.9, TP11.1, XA1.D31
GND: C1.2, C2.2, C3.2, C4.2, D1.2, J1.3, J1.6, J1.12, J2.1, MOD1.10, MOD1.14, R7.2, R8.2, R9.2, U1.3, U1.5, U2.2, U3.1, U3.5, XA1.GND1, XA1.GND2, XA1.GND3, XA1.GND4, XA1.GND5, XA1.GND6
unnamed: J2.2, SW1.1
unnamed: L1.1, U1.4
unnamed: R1.2, U2.7

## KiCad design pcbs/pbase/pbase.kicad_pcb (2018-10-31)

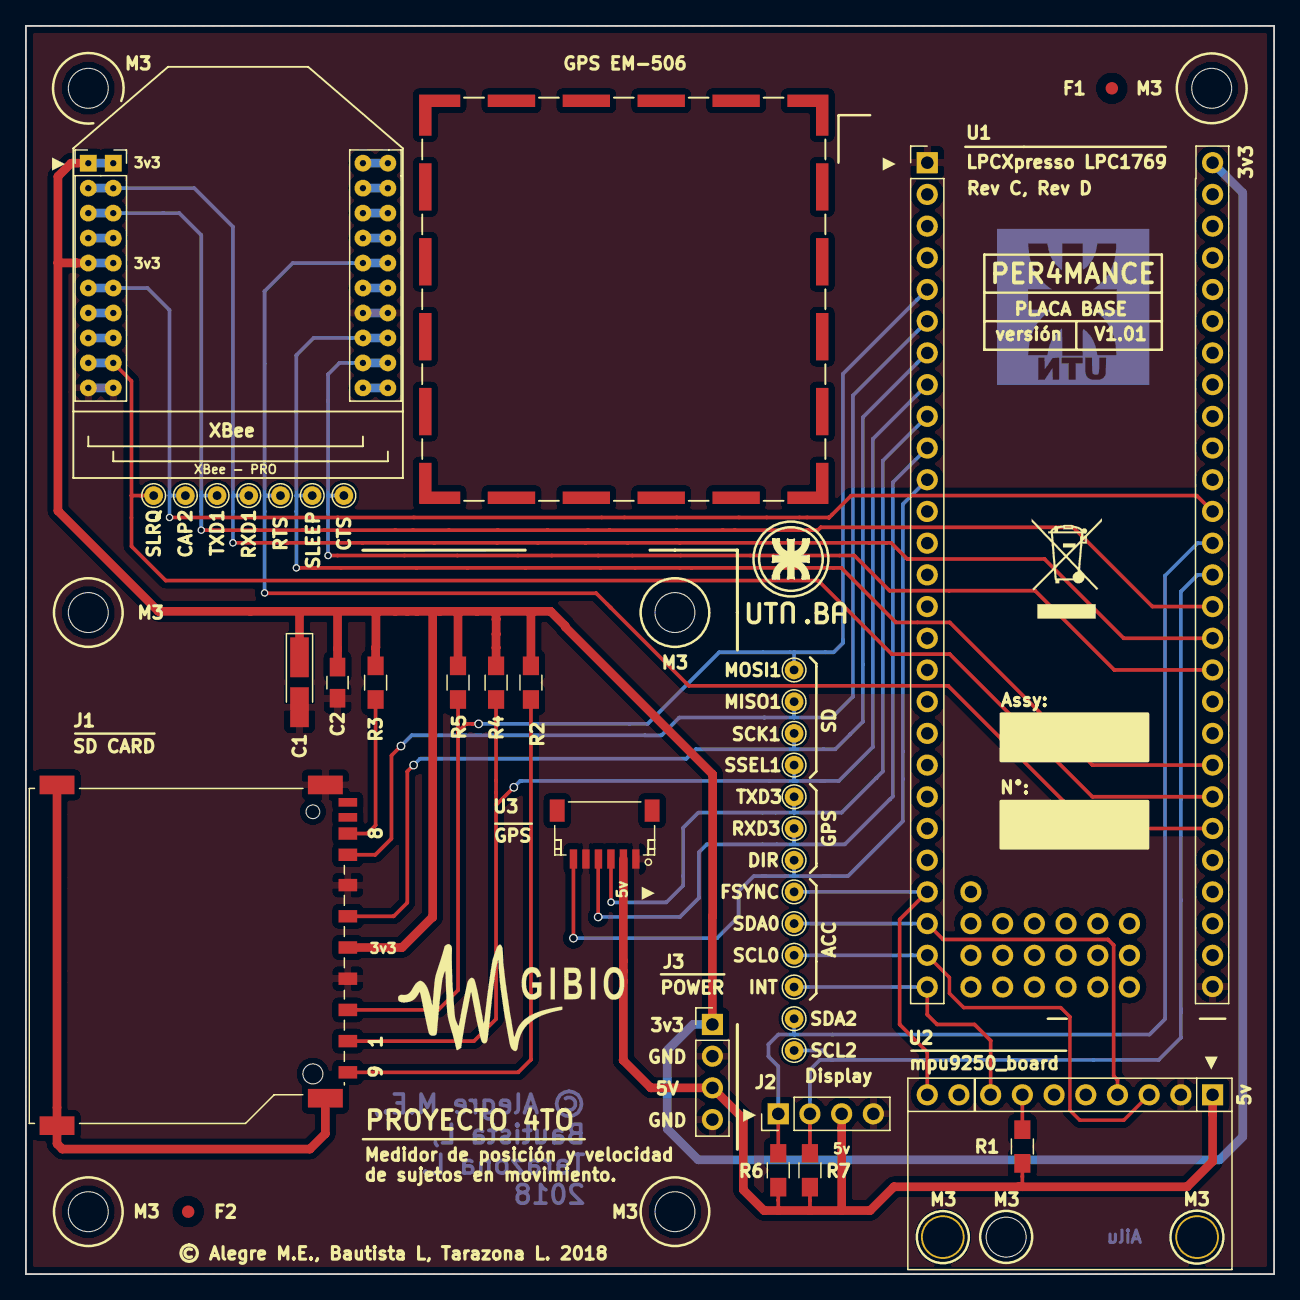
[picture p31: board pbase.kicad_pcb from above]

Board: 2 copper layers, 100.0 x 100.0 mm, 46 parts (0 on the bottom side), 26 nets.

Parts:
C1: 1uF x 16V; CP_Tantalum_Case-A_EIA-3216-18_Hand
C2: 100n; C_0805_HandSoldering
CAP2: CAP2; TestPoint_THTPad_D1.5mm_Drill0.7mm
CTS: CTS1; TestPoint_THTPad_D1.5mm_Drill0.7mm
DIR: DIR; TestPoint_THTPad_D1.5mm_Drill0.7mm
F1, F2: Fiducial_1mm_Dia_2.54mm_Outer_CopperTop
FSYNC: FSYNC; TestPoint_THTPad_D1.5mm_Drill0.7mm
GPS EM-506: Laird_Technologies_BMI-S-204-F_32.00x32.00mm
INT: INT; TestPoint_THTPad_D1.5mm_Drill0.7mm
J1: SD_Card; SD_TE_2041021_edit
J2, J3: Conn_01x04; Socket_Strip_Straight_1x04_Pitch2.54mm
M3, M3#2, M3#3, M3#4, M3#5, M3#6, M3#7: MountingHole_3.2mm_M3_DIN965
MISO1: MISO1; TestPoint_THTPad_D1.5mm_Drill0.7mm
MOD1: XB24CZ7PIT-004; xbee_xb24cz7pit_004
MOSI1: MOSI1; TestPoint_THTPad_D1.5mm_Drill0.7mm
R1: 0R; R_0805_HandSoldering
R2, R3: 10K; R_0805_HandSoldering
R4, R5: 33K; R_0805_HandSoldering
R6: RD1; R_0805_HandSoldering
R7: RD2; R_0805_HandSoldering
RTS: RTS1; TestPoint_THTPad_D1.5mm_Drill0.7mm
RXD1: RXD1; TestPoint_THTPad_D1.5mm_Drill0.7mm
RXD3: RXD3; TestPoint_THTPad_D1.5mm_Drill0.7mm
SCK1: SCK1; TestPoint_THTPad_D1.5mm_Drill0.7mm
SCL0: SCL0; TestPoint_THTPad_D1.5mm_Drill0.7mm
SCL2: SCL2; TestPoint_THTPad_D1.5mm_Drill0.7mm
SDA0: SDA0; TestPoint_THTPad_D1.5mm_Drill0.7mm
SDA2: SDA2; TestPoint_THTPad_D1.5mm_Drill0.7mm
SLEEP: SLEEP; TestPoint_THTPad_D1.5mm_Drill0.7mm
SLRQ: SRQ; TestPoint_THTPad_D1.5mm_Drill0.7mm
SSEL1: SSEL1; TestPoint_THTPad_D1.5mm_Drill0.7mm
TXD1: TXD1; TestPoint_THTPad_D1.5mm_Drill0.7mm
TXD3: TXD3; TestPoint_THTPad_D1.5mm_Drill0.7mm
U1: LPCXpresso_LPC1769_revB; lpc1769_board_revC
U2: acc_mpu9250_board; mpu9250_board
U3: GPS_EM506; JST_SH_SM06B-SRSS-TB_06x1.00mm_Angled

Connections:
+3V3: C1.1, C2.1, J1.4, J3.1, MOD1.1, MOD1.5, R2.1, R3.1, R4.1, R5.1, U1.J-28
+5V: J2.3, J3.3, R1.1, R6.1, R7.1, U2.1, U3.2
/Display/SCL2: J2.2, R7.2, SCL2.1, U1.J-41
/Display/SDA2: J2.1, R6.2, SDA2.1, U1.J-40
/GPS/DIR: DIR.1, U1.J-11, U3.6
/GPS/RXD3: RXD3.1, U1.J-10, U3.4
/GPS/TXD3: TXD3.1, U1.J-9, U3.3
/TarjetaSD/MISO1: J1.7, MISO1.1, U1.J-6
/TarjetaSD/MOSI1: J1.2, MOSI1.1, R5.2, U1.J-5
/TarjetaSD/SCK1: J1.5, SCK1.1, U1.J-7
/TarjetaSD/SSEL1: J1.1, R4.2, SSEL1.1, U1.J-8
/TarjetaSD/data1: J1.8, R3.2
/TarjetaSD/data2: J1.9, R2.2
/Zigbee/CTS: CTS.1, MOD1.12, U1.J-44
/Zigbee/RTS: MOD1.16, RTS.1, U1.J-49
/Zigbee/RXD1: MOD1.2, RXD1.1, U1.J-43
/Zigbee/SLEEP: MOD1.13, SLEEP.1, U1.J-47
/Zigbee/SLRQ: MOD1.9, SLRQ.1, U1.J-48
/Zigbee/TXD1: MOD1.3, TXD1.1, U1.J-42
/acc/FSYNC: FSYNC.1, U1.J-24, U2.10
/acc/INT: INT.1, U1.J-27, U2.8
/acc/SCL0: SCL0.1, U1.J-26, U2.3
/acc/SDA0: SDA0.1, U1.J-25, U2.4
/lpc1769/CAP2.1: CAP2.1, MOD1.6, U1.J-39
GND: C1.2, C2.2, J1.3, J1.6, J1.12, J2.4, J3.2, J3.4, MOD1.10, MOD1.14, U1.J-1, U1.J-54, U2.2, U3.1, U3.5
unnamed: R1.2, U2.7

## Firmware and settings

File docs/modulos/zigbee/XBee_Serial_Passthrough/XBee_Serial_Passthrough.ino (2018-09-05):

/*****************************************************************
XBee_Serial_Passthrough.ino
Set up a software serial port to pass data between an XBee Shield
and the serial monitor.
Hardware Hookup:
  The XBee Shield makes all of the connections you'll need
  between Arduino and XBee. If you have the shield make
  sure the SWITCH IS IN THE "DLINE" POSITION. That will connect
  the XBee's DOUT and DIN pins to Arduino pins 2 and 3.
*****************************************************************/
// We'll use SoftwareSerial to communicate with the XBee:
#include <SoftwareSerial.h>
// XBee's DOUT (TX) is connected to pin 2 (Arduino's Software RX)
// XBee's DIN (RX) is connected to pin 3 (Arduino's Software TX)
SoftwareSerial XBee(2, 3); // RX, TX

void setup()
{
  // Set up both ports at 9600 baud. This value is most important
  // for the XBee. Make sure the baud rate matches the config
  // setting of your XBee.
  XBee.begin(9600);
  Serial.begin(9600);
}

void loop()
{
  if (Serial.available())
  { // If data comes in from serial monitor, send it out to XBee
    XBee.write(Serial.read());
  }
  if (XBee.available())
  { // If data comes in from XBee, send it out to serial monitor
    Serial.write(XBee.read());
  }
}

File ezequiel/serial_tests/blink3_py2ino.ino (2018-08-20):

int ledPin = 13; // usamos un pin de salida al LED
int state = 0; // Variable lectrura serial
 
void setup() {
    pinMode(ledPin, OUTPUT);   //Declara pin de Salida
    digitalWrite(ledPin, LOW); //Normalmente Apagado
    Serial.begin(9600);
}
 
void loop() {
  if(Serial.available())
  {
       state = Serial.read(); 

       //todo a mayusculas
       if(state != 'H' && state != 'L' )
       {
        state -=32;
       }
       
       switch (state)
       {
       case 'L':
       digitalWrite(ledPin, LOW);
       Serial.println("LED: OFF");
       break;
       
       case 'H':
       digitalWrite(ledPin, HIGH);
       Serial.println("LED: ON");
       break;
       
       default:
       Serial.println("Opcion no valida");
       break;
       
       
       }
  } 
 
}

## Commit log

2018-07-10 Modificación en las funciones de los botones que actualizan los valores medios. Se separó en un archivo a parte la clase MyApp_class() -> MyApp.py
2018-07-10 ahora los botones funcionan.
    [testQT.csv, testQT_accX.csv, testQT_escalon.csv]
2018-07-15 cambio de carpetas
    [Costos_proyecto4to.xlsx, LI-ION-Battery.SchDoc, TOP_Schematic.SchDoc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]
2018-07-15 se modificaron los nombres de las subcarpetas del direcotrio docs
2018-07-16 modificacion del codigo. se paracion en carpetas para un mejor desarrollo. Aun faltan corregir bugs pero anda.
    [LI-ION-Battery.SchDoc, TOP_Schematic.SchDoc, acelerometro.csv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]
2018-07-16 cambios en DSP.py y se agrega archivo example4.py en la carpeta de Leandro. Ya se actualizó el código para funcionar con la nueva clase.
2018-07-16 modificacion de DSP.py
2018-07-19 Add files via upload
    Se agrega ejemplo inicial de señal de gps con un filtro fir pasa bajos de orden 10 y su respuesta en frecuencia
    [gps1.csv]
2018-07-20 se modificó la forma de acceder al archivo *.csv
2018-08-09 Se intentó hacer un ejecutable de app.py usando chmod +x app.py
2018-08-13 Modificación a README. Se agrega carpeta pcb
2018-08-13 Creado simbolo de LPCXpresso LPC1769 rev B, KiCad
2018-08-14 se agrega simbolo de LPC1769 revD
2018-08-14 Cambio el nombre de la carpeta lpcxpresso_lpc1769_revb -> lpcxpresso_lpc1769
2018-08-14 Modificación del pinout de todos los simbolos
2018-08-14 Agregado simbolo de acelerometro acc_mu6050 y modificados los demas simbolos
2018-08-18 cambios en ordenamiento de subcarpetas
2018-08-21 Cambios en carpeta sch
    [Accelerom.sch, Display.sch, GPS.sch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]
2018-08-26 cambios sch
    [Accelerom.sch, Display.sch, GPS.sch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]
2018-08-26 archivo de prueba
2018-09-04 add lpc1769 stick footprints
    [familylist_refdes.csv]
2018-09-09 borrado sch
    [Accelerom.sch, Display.sch, GPS.sch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]
2018-09-10 primera finalizacion del esquemático de pbase
    [Display.sch, GPS.sch, TarjetaSD.sch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]
2018-09-11 update 11 sep
    [Display.sch, acc.sch, pwr.sch]
2018-09-13 Test points
    [Display.sch, PCB Layout Checklist_PBASE.xlsx, acc.sch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]
2018-09-13 cambios a sch
    [Display.sch, GPS.sch, TarjetaSD.sch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]
2018-09-17 modificaciones varias al acc mpu-6050
    [acc.sch]
2018-09-17 modificadas librerias de acc
2018-09-17 reemplazado acc por mpu9250
    [Display.sch, GPS.sch, TarjetaSD.sch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]
2018-09-17 sch annotate v1.1
    [Display.sch, GPS.sch, TarjetaSD.sch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]
2018-09-18 agregados footprints gps y mpu9250
2018-09-19 pbase pcb inicio
    [Display.sch, GPS.sch, TarjetaSD.sch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]
2018-09-19 BOM agregado
    [pbase.csv]
2018-09-21 pbase edits
    [lpc1769.sch, pbase.kicad_pcb, pwr.sch]
2018-09-21 PCB PLACING V1
    [PCB Layout Checklist_PBASE.xlsx, TarjetaSD.sch, lpc1769.sch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]
2018-09-23 pcb replacing
    [pbase.kicad_pcb]
2018-09-25 pcb fin 1
    [PCB Layout Checklist_PBASE.xlsx, TarjetaSD.sch, pbase.kicad_pcb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]
2018-09-26 pbase pcb finalizado v1
    [PCB Layout Checklist_PBASE.xlsx, pbase.kicad_pcb]
2018-09-27 pcb finalizado
    [pbase.kicad_pcb]
2018-09-27 PCB correcion pista 3V3
    [PCB Layout Checklist_PBASE.xlsx, pbase.kicad_pcb]
2018-09-27 PLACA FINALIZADA
    [PCB Layout Checklist_PBASE.xlsx, pbase.kicad_pcb]
2018-09-30 movida carpeta lpc_info a docs
    [potencia_proyecto_lpc.ods]
2018-09-30 pbase lpc drc
    [pbase.kicad_pcb]
2018-10-01 pequeños cambios
    [GPS.sch, TarjetaSD.sch, Zigbee.sch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]
2018-10-01 agregado footprint mpu9250
2018-10-01 cambiado footprint acc mpu9250, agregado mounting hole para mpu 6050
    [pbase.kicad_pcb]
2018-10-01 pcb lpc finalizado sin llaves
    [pbase.kicad_pcb]
2018-10-02 PCBs pbase y pbase-ino FINALIZADOS, archivos gerbers en zip dentro del directrio /pcbs
    [PCB_Layout_Checklist_PBASE-INO.xlsx, TarjetaSD.sch, arduino-MEGA.sch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]
2018-10-12 pcb cargador
    [bateria.sch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]
2018-10-31 pdfs realizados
    [Display.sch, GPS.sch, PCB Layout Checklist.xlsx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]
2018-10-31 agregados los BOM
    [cargador.csv, pbase-ino.csv, pbase.csv]
2018-10-31 correcciones en el BOM
    [pbase-ino.csv, pbase.csv]
2018-10-31 pdfs de pcbs finalizados. Contienen SCH, PCB y BOM.
    [GPS.sch, pbase-ino.kicad_pcb, pbase.kicad_pcb]
2018-11-01 correcciones en los pdfs de los pcb
    [bateria.sch, cargador.csv, cargador.kicad_pcb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]

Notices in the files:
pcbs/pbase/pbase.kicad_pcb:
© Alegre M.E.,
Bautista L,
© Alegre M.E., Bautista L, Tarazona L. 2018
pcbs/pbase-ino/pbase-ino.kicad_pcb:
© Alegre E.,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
